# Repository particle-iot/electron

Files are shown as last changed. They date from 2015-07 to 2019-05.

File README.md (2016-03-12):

# Electron

The Electron is a tiny cellular development kit based around U-Blox's SARA U-series (3G) or G-series (2G) cellular modem module and a STM32F205 ARM Cortex M3 microcontroller.

The Electron has a footprint which is a drop-in compatible with the Particle Photon or Core.

Compared to the Particle Photon, the Electron introduces additional hardware features and changes:

1. JST LiPo battery connector.
2. Switch-mode battery charge management and system power path management circuit.
3. Fuel gauge circuit for lithium batteries.
4. Nano-SIM connector.
5. Access to USB data lines. 
6. 12 additional GPIO Pins.
7. 4 additional ADC channels.
8. 6 Timer channels exposed.
9. 2 additional UART peripherals.
10. 1 additional SPI and CAN peripheral.

A detailed description of the pin mapping can be found in **electron-pinmap_v1** spreadsheet.
* Sheet 1: Overview of the Electron pin-out.
* Sheet 2: Overview of the Photon pin-out for comparison.

### Pin Descriptions:
- **VIN:** This is the power supply pin to the Electron with a voltage range of 3.6 to 5.5VDC (internally regulated down to 3.3VDC). When the Electron is powered via its USB port, this pin will *ouput* a voltage of approximately 4.7VDC. Why 4.7 and not 5? Well, the actual voltage will be the USB voltage, which is normally 5, minus the forward voltage drop (0.3V) of the protection diode.
- **RST:** This is an active-low reset pin for the Electron.
- **VBAT:** Supply to the internal RTC, backup registers and SRAM (1.8 to 3.3VDC).
- **3V3:** This pin is the output of the on-board regulator. When powering the Photon via VIN or the USB port, this pin will *output* a voltage of 3.3VDC.
- **WKP:** This is an active-high input that allows you to wakeup the module from sleep/deep sleep modes. When not used as a WAKEUP, this pin can also be used as a digital GPIO, ADC input or PWM.
- **A0 - A5:** These can be used as digital GPIOs, ADC inputs. Alternate functions include: SPI, PWM and DAC.
- **B0 - B5:** These can be used as digital GPIOs, partial ADC inputs, partial PWM outputs.
- **C0 - C5:** These can be used as digital GPIOs.
- **D0 - D7:** These can be used as digital GPIOs. Alternate functions include: UART, SPI, I2C, PWM and CAN. 
- **DAC:** This pin can be used as a digital GPIO, ADC input or as a DAC ouput.
- **RX:** Primarily used as UART RX, but can also be used as a digital GPIO, ADC input or PWM.
- **TX:** Primarily used as UART TX, but can also be used as a digital GPIO, ADC input or PWM.

Please review the pinmap spreadsheet to better understand the alternate functions of the GPIO pins.

### Eagle (schematic, pcb layout and drc):
**eagle** contains the history of Electron designs and **electron_v020** is the latest design.  The **libraries** folder contains the Eagle library for parts used on the Electron.

#License

Designed by Particle. Distributed under a Creative Commons Attribution, Share-Alike license.
Development kits based on this product should be distributed under a similar license.
Commercial products using the Electron as a reference design need not comply with this license; further questions can be sent to hello@particle.io.
Check license.txt for more information.

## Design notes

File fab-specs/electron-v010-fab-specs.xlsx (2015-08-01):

F A B R I C A T I O N D E T A I L S
Customer | : | Particle Industries, Inc.
ATTN | :
Phone # | :
项目名称 Part # | : | electron
版本 Revision | : | v010
层数 # of Layers | : | 4
材料类型 Material Type | : | 370HR
板子厚度 Board Thickness | : | 0.0625"
镀层 Finish Plating | : | ENIG (化镍浸金)
金手指 Gold Fingers | : | 0
板子叠层 Board Stackup | : | 0.018mm - TOP COPPER (GTL) 顶层
 |  | 0.19mm - 7628M/46 x 1
 |  | 0.035mm - LAYER 2 COPPER (G2L) 第二层
 |  | 1.0 to 1.10mm - Core
 |  | 0.035mm - LAYER 3 COPPER (G15L) 第三层
 |  | 0.19mm - 7628M/46 x 1
 |  | 0.018mm - BOTTOM COPPER (GBL) 底层
阻抗控制 Controlled Impedance |  | Yes - 50 ohms on RF Traces (see rf_nets.pdf) 具体参照rf_nets.pdf
介质控制 Controlled Dielectric |  | Yes (part of Controlled Impedance)
最小线宽线距 Min. Width/Spacing | : | 6/6 mils
孔的数量 # Holes | :
最小的孔尺寸 Smallest Hole Size | :
最大的孔尺寸 Largest Hole Size | :
孔的种类 # of Hole Sizes | :
板子尺寸 Board Dimensions | : | 2.03cm x 5.08 cm
排版后的尺寸 Array Size | :
排版的数量 # PCS/Array | : | 10
排版方式 Panelization method | :
插槽 Slots/Cutouts | : | 2 plated slots - 0.020" x 0.047" （2个电镀的槽）
阻焊 Solder Mask | :
丝印 Silk Screen | : | LPI Cyan Top and Bottom（亮青色，参照样品，实际需要用曝光的工艺来做“丝印”）
顶部SMD焊盘的数量 SMD pads Top | :
底部SMD焊盘的数量 SMD pads Bot | :
最小的SMD焊盘的间距 Min. SMD pitch | :
Fabrication | :
齿形的孔 Castellated Holes | : | Yes
最小的齿形空的尺寸Min. Castellated Hole Size | : | 25 mils
电性测试 Electrical Test | : | Yes
订单数量 Quantity |  | 500
交期 Lead Time |  | TBD
Notes:
1) Panelized and v-scored on short sides, routed castellated edges on long sides. 需要进行多片排版，短边留V-CUT的槽，长边沿着齿状边切掉。
2) Do not clip silk screen more than 2-3 mils around exposed copper. 在暴露的铜旁边，对丝印的修剪不可以大于2-3 mils

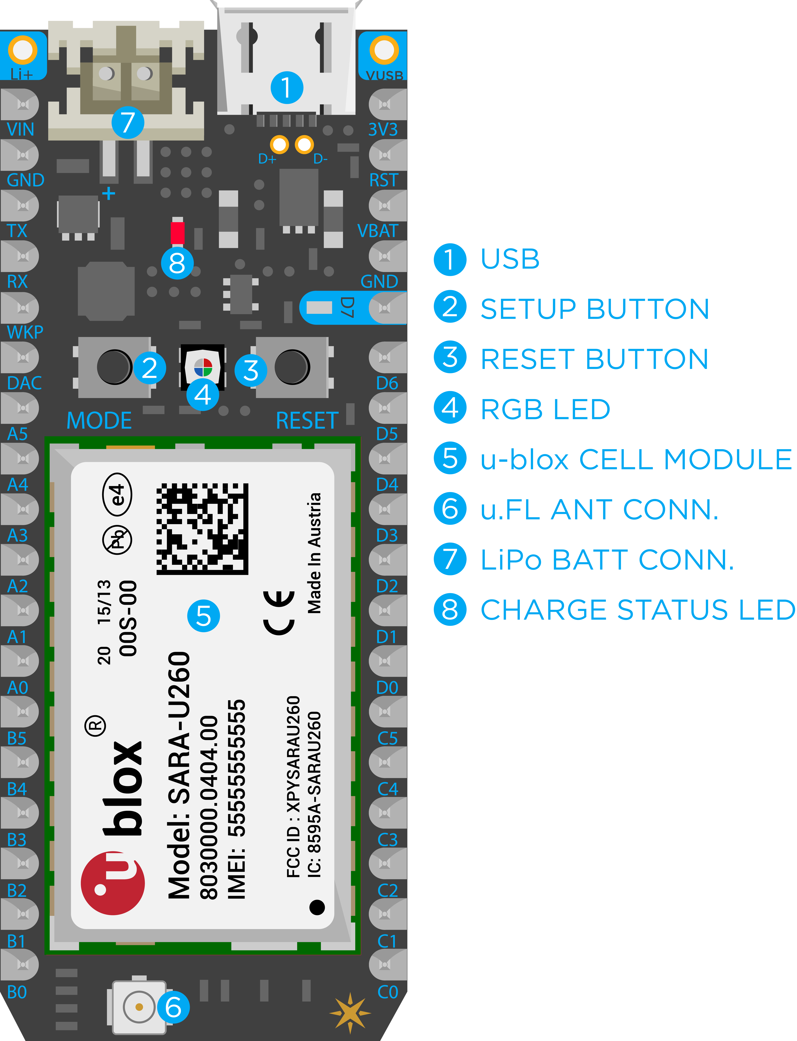
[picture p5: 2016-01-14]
docs/images/electron_pin_markings.png

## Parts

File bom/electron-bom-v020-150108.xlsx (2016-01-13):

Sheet: ELECTRON
 | NAME | ELECTRON
PCBA
 | IDENTIFIER | DESCRIPTION | VALUE | V | A | W | TOL | PACKAGE ID | DESIGNATOR | QTY | MANUFACTURER | MANUFACTURER P/N | CHANGE HISTORY ON 1/8 | CHANGE HISTORY ON 12/8
 | CAPACITOR | Ceramic Capacitor | 0.1uF | 6.3V |  |  | 10% | 0402 | C14, C17, C18, C19, C2, C20, C21, C22, C29, C30, C31, C6, C8, C9 | 14 | Fenghua | 0402B104K160NT
 | CAPACITOR | Ceramic Capacitor | 10nF | 6.3V |  |  | 10% | 0402 | C1, C38 | 2 | Fenghua | 0402B103K500NT
 | CAPACITOR | Ceramic Capacitor, X5R, Low ESR (<70 mΩ) | 10uF | 6.3V |  |  | 10% | 0603 | C23, C24, C27, C40, C41 | 5 | Yageo | CC0603KRX5R5BB106
 | CAPACITOR | Ceramic Capacitor | 12pF | 6.3V |  |  | 10% | 0402 | C33, C34 | 2 | Fenghua | 0402CG120J500NT
 | CAPACITOR | Ceramic Capacitor | 15pF | 6.3V |  |  | 10% | 0402 | C16 | 1 | Fenghua | 0402CG150J500NT
 | CAPACITOR | Ceramic Capacitor | 1uF | 6.3V |  |  | 10% | 0402 | C37, C39 | 2 | Fenghua | 0402X105K6R3NT
 | CAPACITOR | Ceramic Capacitor, X5R, Low ESR (<70 mΩ) | 1uF | ≥25V |  |  | 10% | 0603 | C4 | 1 | Yageo | CC0603KRX5R8BB105
 | CAPACITOR | Ceramic Capacitor, X5R, Low ESR (<70 mΩ) | 2.2uF | 6.3V |  |  | 10% | 0402 | C32, C35 | 2 | Yageo | CC0402KRX5R5BB225
 | CAPACITOR | Ceramic Capacitor | 20pF | 6.3V |  |  | 10% | 0402 | C26, C28 | 2 | Fenghua | 0402CG200J500NT
 | CAPACITOR | Ceramic Capacitor, X5R, Low ESR (<70 mΩ) | 22uF | 6.3V |  |  | 10% | 0603 | C5 | 1 | Samsung | CL10A226KQ8NRNE
 | CAPACITOR | Tantalum Capacitor | 220uF | 6.3V |  |  | 10% | 2312 (6032 metric) | C3 | 1 | AVX | TAJC227K006
 | CAPACITOR | Ceramic Capacitor, X5R, Low ESR (<70 mΩ) | 4.7uF | 6.3V |  |  | 10% | 0402 | C36 | 1 | Samsung | CL05A475KQ5NRNC
 | CAPACITOR | Ceramic Capacitor, X5R, Low ESR (<70 mΩ) | 4.7uF | 6.3V |  |  | 10% | 0603 | C25 | 1 | Yageo | CC0603KRX5R5BB475
 | CAPACITOR | Ceramic Capacitor | 47nF | 6.3V |  |  | 10% | 0402 | C7 | 1 | Fenghua | 0402B473K160NT
 | CAPACITOR | Ceramic Capacitor | 47pF | 6.3V |  |  | 10% | 0402 | C10, C11, C12, C13 | 4 | Fenghua | 0402CG470J500NT
 | CAPACITOR | Ceramic Capacitor | 68pF | 6.3V |  |  | 10% | 0402 | C15 | 1 | Fenghua | 0402CG680J500NT
 | CONNECTOR | JST Connector | 2-pin |  |  |  |  | SMD, 2-pin, Vertical | JP4 | 1 | Kaweei | CW2001-02T-M01-D
 | CONNECTOR | Male Header (0.1" pitch) x 18 pins (B1-B5, A0-A4) | 1x18 |  |  |  |  | 1x18, 0.1" pitch | JP1 | 1 | Kaweei | CP25411-18G-S116A-A
 | CONNECTOR | Male Header (0.1" pitch) x 18 pins (D0-D4, C1-C5) | 1x18 |  |  |  |  | 1x18, 0.1" pitch | JP2 | 1 | Kaweei | CP25411-18G-S116B-A
 | CONNECTOR | USB Micro Connector with Slots, SMD |  |  |  |  |  | USB-MICROB-SLOT-HOLE | X1 | 1 | Kaweei | CMCUSB-5BFM2G-01-D
 | CONNECTOR | uFL Connector, IPEX-20279-001E, SMD |  |  |  |  |  | SMD | J2 | 1 | Kaweei | P1163-0140R
 | CONNECTOR | Nano SIM Card Slot |  |  |  |  |  | 10mm x 12.3mm | J1 | 1 | Kaweei | CSIM2545-06S-D
 | CRYSTAL | 26MHz, 18pF Load Capacitance, SMD5032, 4 pad | 26MHz |  |  |  | <±20ppm | 4-SMD, 5.0 x 3.2mm | Y2 | 1 | Song Ji | SJSMD5026M00018F20
 | CRYSTAL | 32.768KHz, 12.5pF Load Capacitance, SMD3215, 2 pad | 32.768KHz |  |  |  | <±20ppm | 2-SMD, 1.5 x 3.2mm | Y1 | 1 | Song Ji | SJ FC1332K012F520P
 | DIODE | Schottky Diode |  | 30V | 3A |  |  | DO-220AA | U$3 | 1 | Vishay | SS3P3-M3/84A
 | IC | Buffer |  |  |  |  |  | SC-70-5 | U5, U6 | 2 | Texas Instruments | SN74LVC1G07DCKR
 | IC | IC 2-Wire Fuel Gauge |  |  |  |  |  | TDFN-8 | U4 | 1 | Maxim | MAX17043G+T
 | IC | GSM Module |  |  |  |  |  | 16 x 26 x 3mm | U1 | 1 | u-blox | SARA-G350 SARA-U260 SARA-U270
 | IC | IC Bus Transceiver |  |  |  |  |  | 16-UQFN | U2, U8 | 2 | Texas Instruments | SN74AVC4T245RSVR
 | IC | Microcontroller |  |  |  |  |  | LQFP64 | U3 | 1 | ST Microelectronics | STM32F205RGT6TR
 | IC | Power Management IC (PMIC) |  |  |  |  |  | 24VQFN | U$1 | 1 | Texas Instruments | BQ24195RGER
 | IC | Load Switch |  |  |  |  |  | SC70-5 | U9 | 1 | Texas Instruments | TPS22942DCKR
 | IC | Voltage Regulator |  | 1A |  |  |  | 6-SON (2x2) | U$5 | 1 | Texas Instruments | TPS62291DRVR
 | INDUCTOR | Power Wirewound Inductor, 100KHz, Ferrite, 1212 (for 3V3 regulator) | 2.2uH |  | 1.5A |  | 20% | 3.0 mm x 3.0 mm | U$6 | 1 | Taiyo Yuden | NR3015T2R2M
 | INDUCTOR | Power Inductor (for PMIC) | 2.2uH |  | 4A |  |  | 4.45mm x 4.06mm | U$4 | 1 | Bourns, Inc. | SRP4020TA-2R2M
 | LED | Blue, SMD | Blue |  |  |  |  | 0603 | LED1 | 1 | Everlight | 19-217/BHC-ZL1M2RY/3T
 | LED | Red, SMD | Red |  |  |  |  | 0603 | LED3 | 1 | Everlight | 19-217/R6C-AL1M2VY/3T
 | LED | LED RGB, SMD | RGB |  |  |  |  | 4-PLCC (3.2 mm x 2.8mm) | LED2 | 1 | Cree | CLMVB-FKA-CFHEHLCBB7A363
 | PCB | FR4 4-Layer Photon PCB, 2-sided, matte black soldermask, cyan silkscreen |  |  |  |  |  | 20 mm x 50 mm | PCB1 | 1 | Truly
 | RESISTOR | Resistor | 0R |  |  | 1/16W |  | 0201 | R32 | 1 | Fenghua |  | ADDED A NEW PART
 | RESISTOR | Resistor | 100k |  |  | 1/16W | 5% | 0402 | R1 | 1 | Fenghua | RC-02W104JT
 | RESISTOR | Resistor | 10K |  |  | 1/16W | 5% | 0402 | R3, R8, R15, R16, R17, R19, R21, R24, R25, R27, R28, R29, R30, R31 | 14 | Fenghua | RC-02W103JT
 | RESISTOR | Resistor | 150R |  |  | 1/4W | 1% | 0603 | R22 | 1 | Vishay | CRCW0603150RFKEAHP
 | RESISTOR | Resistor | 1K |  |  | 1/16W | 5% | 0603 | R23 | 1 | Fenghua | RC-03K102JT
 | RESISTOR | Resistor | 1K |  |  | 1/16W | 5% | 0402 | R10, R11, R12, R9 | 4 | Fenghua | RC-02W102JT
 | RESISTOR | Resistor | 2.2K |  |  | 1/16W | 5% | 0402 | R4 | 1 | Fenghua | RC-02W222JT
 | RESISTOR | Resistor | 22R |  |  | 1/16W | 1% | 0402 | R5, R6 | 2 | Fenghua | RC-02W22R0FT
 | RESISTOR | Resistor | 330R |  |  | 1/16W | 1% | 0402 | R2 | 1 | Fenghua | RC-02W3300FT
 | RESISTOR | Resistor | 4K7 |  |  | 1/16W | 5% | 0402 | R13, R14 | 2 | Fenghua | RC-02W472JT
 | RESISTOR | Resistor | 5.49K |  |  | 1/16W | 1% | 0402 | R18 | 1 | Fenghua | RC-02W5491FT
 | SWITCH | Tactile Switch, Black Button | 160gF |  |  |  |  | 3.6mm x 3.1mm | MODE, RESET | 2 | Haoyu | TS-1185A-C
ACCESSORIES
 | IDENTIFIER | DESCRIPTION | VALUE | V | A | W | TOL | PACKAGE ID | DESIGNATOR | QTY | MANUFACTURER | MANUFACTURER P/N | CHANGE HISTORY ON 1/8 | CHANGE HISTORY ON 12/8
 | ACCESSORY | Li-Po Battery with JST Connector (2.0mm spacing, 2 pin), 3.7V, 2000mAh |  |  |  |  |  | 51mm x 34mm x 11.3mm | BAT1 | 1 | PKCell | LIPO 103450 2000mAh 3.7V
 | ACCESSORY | Mini Breadboard, White, 400pt tie point, 3.5 x 4.5cm |  |  |  |  |  | 3.5 x 4.5cm | ACC1 | 1 | Ningbo Everest | N/A
 | ACCESSORY | USB Micro-B Cable, 0.5m, White with Molded Logo |  |  |  |  |  | USB Micro-B, 0.5m | ACC2 | 1 | HOP Electronics | N/A
 | ANTENNA | Antenna - Penta band 850/900/1800/1900/2100 MHz |  |  |  |  |  | IPEX MHFI (U.FL) | ANT1 | 1 | Taoglas | PC104.07.0165C
 | DIODE (LED) | White, high brightness | White |  |  |  |  | 5mm DIP |  | 1 | ZHIHENG | ZH-504UW/006-A70
 | RESISTOR | Axial Resistor | 220R |  |  |  |  | Axial DIP |  | 2 | Chianchia | CF1/4W220RJT52
 | RESISTOR | Photoresistor |  |  |  |  |  | 5mm DIP |  | 1 | HAIWANG | MJ5517
 | SIM | Nano SIM Card |  |  |  |  |  | Nano SIM | SIM1 | 1 | Telefonia | N/A
PACKAGING
 | IDENTIFIER | DESCRIPTION | VALUE | V | A | W | TOL | PACKAGE ID | DESIGNATOR | QTY | MANUFACTURER | MANUFACTURER P/N | CHANGE HISTORY ON 1/8 | CHANGE HISTORY ON 12/8
 | PACKAGING | Transparent Plastic Box |  |  |  |  |  | 145 x 90 x 40mm |  | 1 | Youter | YS-E503-1
 | PACKAGING | Internal "ribbon" card stock, cyan with white printing |  |  |  |  |  |  |  | 1 | Mei Ya
 | PACKAGING | Internal anti-static foam insert, top |  |  |  |  |  |  |  | 1 | Sai Fu Ke Si
 | PACKAGING | Internal anti-static foam insert, bottom |  |  |  |  |  |  |  | 1 | Sai Fu Ke Si
 | PACKAGING | Electron Kit Project Card |  |  |  |  |  | Custom |  | 1 | Mei Ya
 | STICKER | "STICK-VINYL-2IN" sticker, 2", Circular, PVC - 5cm |  |  |  |  |  | Circular 2" |  | 1 | Mei Ya
 | PACKAGING | Cardboard box for battery |  |  |  |  |  | TBD |  | 1
 | PACKAGING | Small ziploc static bag for Li-Po battery |  |  |  |  |  |  |  | 1
 | STICKER | "Don't Charge Unattended" Sticker |  |  |  |  |  |  |  | 1
 | STICKER | UPC Sticker for Li-Po Battery (2000mAh) |  |  |  |  |  | 40 mm x 20 mm |  | 1 | Mei Ya | UPC - 724131462352
 | PACKAGING | Small ziploc static bag for starter project components |  |  |  |  |  | 35mm*86mmx0.075mm |  | 1 | Hengmeifeng | ZB2050
 | STICKER | Electron Product Sticker (UPC/Certifications) |  |  |  |  |  |  |  | 1 | Mei Ya | G350 (2G) - 724131462277 U260 (3G N.A.) - 724131462284 U270 (3G World) - 724131462383
 | STICKER | Unique Barcode Sticker (DYMO 30346) |  |  |  |  |  | 1/2" x 1-7/8" |  | 1
 | PACKAGING | Electron box sleeve |  |  |  |  |  |  |  | 1 | Mei Ya
 | PACKAGING | Sticker for SIM card |  |  |  |  |  | 8.5*5.4cm |  | 1 | Mei Ya |  |  | New added part
 | STICKER | UPC Sticker for the Electron |  |  |  |  |  | 40 mm x 20 mm |  | 1 | Mei Ya | G350 (2G) - 724131462277 U260 (3G N.A.) - 724131462284 U270 (3G World) - 724131462383
 | PACKAGING | Transparent Plastic Wrapping |  |  |  |  |  |  |  | 1
 | STICKER | Li-Po Battery Safety Sticker |  |  |  |  |  | 105 x 74mm |  | 1
 | RESISTOR | Resistor | 0R |  |  | 1/16W | 0.05 | 0402 |  | 0 | Fenghua | RC-02000JT

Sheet: CHANGELOG
Subject: | Electron
Project Name: | ELECTRON
BOM Rev.: | 2015-08-20
PCB Rev.: | v011
Date: | 2016-01-08
Prepared by: | Will Hart |  |  |  |  |  | Taoglas | PC104.07.0165C
Project Name |  |  |  | PARTICLE ELECTRON
Item | BOM Revision |  | Project Name | Change Details | Date | Responsible
 | Old | New
1 | electron-bom-v010 | electron-bom-v010-150731 | ELECTRON | Added power, voltage, and tolerance specifications to resistors and capacitors | 2015-07-31 | Will
2 | electron-bom-v010 | electron-bom-v010-150731 | ELECTRON | Changed part number on the Nano SIM from the "loose" to the "tight" connector (CSIM2545-06S-X) | 2015-07-31 | Will
3 | electron-bom-v010 | electron-bom-v010-150731 | ELECTRON | Updated specifications and preferred/alternate part numbers on both power inductors (U$4 and U$6) | 2015-07-31 | Will
4 | electron-bom-v010 | electron-bom-v010-150731 | ELECTRON | Added UPC information to the UPC sticker | 2015-07-31 | Will
5 | electron-bom-v010 | electron-bom-v010-150731 | ELECTRON | Added antenna part specifications to the BOM | 2015-07-31 | Will
6 | electron-bom-v010 | electron-bom-v010-150731 | ELECTRON | Updated Li-Po battery specifications to PKCell part | 2015-07-31 | Will
7 | electron-bom-v010-150731 | electron-bom-v010-150803 | ELECTRON | Updated PMIC Inductor P/N and specs (U$4) | 2015-08-03 | Will
8 | electron-bom-v010-150803 | electron-bom-v010-150805 | ELECTRON | Added MFG and P/Ns for all passive components | 2015-08-05 | Will
9 | electron-bom-v010-150803 | electron-bom-v010-150805 | ELECTRON | Deleted part number U$7 from the BOM | 2015-08-05 | Will
10 | electron-bom-v010-150803 | electron-bom-v010-150805 | BAT2000 | Added BAT2000 SKU tab and populated with BOM items | 2015-08-05 | Will
11 | electron-bom-v010-150803 | electron-bom-v010-150805 | ELECTRON | Updated power tolerances for resistors | 2015-08-05 | Will
12 | electron-bom-v010-150803 | electron-bom-v010-150805 | ELECTRON | Removed 2000mAh hour from ELECTRON BOM and transferred to the BAT2000 BOM | 2015-08-05 | Will
13 | electron-bom-v010-150803 | electron-bom-v010-150805 | ELECTRON | Removed PKG1 and PKG2 (Static bag and static bubble bag) from the ELECTRON BOM | 2015-08-05 | Will
14 | electron-bom-v010-150803 | electron-bom-v010-150805 | TBD | Added TBD section | 2015-08-05 | Will
15 | electron-bom-v010-150805 | electron-bom-v010-150807 | ELECTRON | Updated C5 from 20uF to 22uF to match manufacturer availability | 2015-08-07 | Will
16 | electron-bom-v010-150807 | electron-bom-v010-150812 | ELECTRON | Updated quantity field for resistors and capacitors to match the correct number of designators on the board | 2015-08-12 | Will
17 | electron-bom-v010-150812 | electron-bom-v011-150820 | ELECTRON | Changed the value of C40 and C41 from 2.2uH to 10uH | 2015-08-20 | Will
18 | electron-bom-v010-150812 | electron-bom-v011-150820 | ELECTRON | Added cross part numbers to low ESR parts | 2015-08-20 | Will
19 | electron-bom-v010-150812 | electron-bom-v011-150820 | ELECTRON | Changed the specifications and part number of power inductor for 3V3 inductor (U$6) | 2015-08-20 | Will
20 | electron-bom-v011-150820 | electron-bom-v011-150830 | ELECTRON | Deleted extra antenna P/Ns | 2015-08-23 | Will
21 | electron-bom-v011-150820 | electron-bom-v011-150830 | ELECTRON | Deleted Fenghua cross part numbers on capacitors. | 2015-08-31 | Will
22 | electron-bom-v011-150830 | electron-bom-v012-150908 | ELECTRON | Added new BAT2000 parts to the ELECTRON BOM since it will all be packaged as one unit | 2015-09-08 | Will
23 | electron-bom-v011-150830 | electron-bom-v012-150908 | ELECTRON | Updated part number for C32, C35 to CC0402KRX5R5BB225 to match the 0402 specification | 2015-09-08 | Will
24 | electron-bom-v011-150830 | electron-bom-v012-150908 | ELECTRON | Split 1x18 header into two line items with slightly different part numbers to reflect the different printing requirements | 2015-09-08 | Will
25 | electron-bom-v012-150908 | electron-bom-v015-150922 | ELECTRON | Updated P/N of R18 from RS-02W5491FT to RC-02W5491FT | 2015-09-22 | Will
26 | electron-bom-v015-150922 | electron-bom-v016-151026 | ELECTRON | Updated qty and designators for 0K, 4K7, and 10K resistors | 2015-10-26 | Will
27 | electron-bom-v016-151026 | electron-bom-v017-151102 | ELECTRON | Updated quantity of 10K and 4K7 resistors and deleted all 0R resistors | 2015-11-02 | Mohit
28 |  | electron-bom-v017-151130 | ELECTRON | Updated quantity of 10K resistors from 13 to 14 | 2015-11-30 | Mohit
29 |  | electron-bom-v017-151130 | ELECTRON | Added a new part, load switch - TPS22942DCKR | 2015-11-30 | Mohit
30
31
32
33
34
35
36
37
38
39
40
41
42
43
44
45
46
47
48
49
50
51
52
53
54
55
56
57
58
59
60
61
62
63
64
65
66
67
68
69
70
71
72
73
74
75
76
.end of doc.

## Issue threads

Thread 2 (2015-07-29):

Optimize the solder pads to mitigate risk of contact between solder pins and u-blox module

brandoaire, 2015-07-29:
As soon as we have a proposed solution, let me know so that we can check to be sure it's compatible with whatever the tolerances of the wave solder fixtures is

Closed 2015-07-31.

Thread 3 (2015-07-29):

Current SIM Card holder part doesn't create reliable connection

brandoaire, 2015-07-29:
Going to test the "tighter" version of the Kaweei SIM card slot part first, then can consider GCT part as higher cost alternate.  @jenesaisdiq will ship the parts to @technobly on 7/29

technobly, 2015-08-01:
Tested the 2nd more snug sample, and it's a dang nice sim card holder!  All the problems with the previous one not allowing the card to fully insert are resolved with this one.  And the contacts are smooth and snug.

Closed 2015-08-01.

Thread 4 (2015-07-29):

Expose 5V USB pin alongside D+ and D-?

brandoaire, 2015-07-29:
Would be useful to have a regulated 5V supply now that VIN has a diode on the input line from the USB micro.  Richard suggested placement in line with the header pins in the top right corner, but not populated.

Closed 2015-07-30.

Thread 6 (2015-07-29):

Consolidate passive package sizes

brandoaire, 2015-07-29:
There are a bunch of passives that have both 0603 and 0402 components of the same value.  We can simplify our BOM by consolidating to a single package size.

brandoaire, 2015-07-29:
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

satishgn, 2015-07-30:
0603 footprint is used for certain parts since they are directly connected across high voltage/current 3.8V/3.3V regulator & fuel gauge ICs and using 0402 footprint without sufficient rating could be an issue. Let's discuss tonight and take a decision on this issue.

Closed 2015-07-30.

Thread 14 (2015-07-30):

Test all pins as GPIO to ensure proper connection

technobly, 2015-07-30:
I ran through the pins associated with the Photon on the Electron with the attached test app (D0-D7 and A0-A7), and all of them work except for:

- [x] A0-A7 work as expected.
- [x] D0-D3, D6-D7 work as expected.
- [x] D5 had voltage on it and wouldn't go HI / LOW properly but it does move when commanded
- [x] D4 has 3.3V on it and won't pull low but it wiggles when commanded
- [x] RX, TX work as expected.

These may have some kind of solder issue.  This was v004 Dev Electron, will re-test on v009.
Update: D4/D5 had some soldering or measurement issue because they work fine on v009 hardware.

- [x] Also need to test B0-B5 and C0-C5, not mapped in PIN_MAP yet.
- [x] Update: B0-B5 and C0-C5 work as expected.

```cpp
#include "application.h"

bool s = false;
String command = "";

SYSTEM_MODE(MANUAL);

char lookup[38][16] = {
	"D0  = PB7",
	"D1  = PB6",
	"D2  = PB5",
	"D3  = PB4",
	"D4  = PB3",
	"D5  = PA15",
	"D6  = PA14",
	"D7  = PA13",
	"ID8 = NULL",
	"ID9 = NULL",
	"A0  = PC5",
	"A1  = PC3",
	"A2  = PC2",
	"A3  = PA5",
	"A4  = PA6",
	"A5  = PA7",
	"A6  = DAC = PA4",
	"A7  = WKP = PA0",
	"RX  = PA10",
	"TX  = PA9",
	"SETUP",
	"RGBR",
	"RGBG",
	"RGBB",
	"B0  = PC8",
	"B1  = PC6",
	"B2  = PB0",
	"B3  = PB1",
	"B4  = PC0",
	"B5  = PC1",
	"C0  = PD2",
	"C1  = PC12",
	"C2  = PC11",
	"C3  = PC10",
	"C4  = PB9",
	"C5  = PB8"
};

#if 0
/* TXD_UC        - 36 */ { GPIOB, GPIO_Pin_10, GPIO_PinSource10, NONE, NONE, TIM2, TIM_Channel_3, PIN_MODE_NONE, 0, 0 },
/* RXD_UC        - 37 */ { GPIOB, GPIO_Pin_11, GPIO_PinSource11, NONE, NONE, TIM2, TIM_Channel_4, PIN_MODE_NONE, 0, 0 },
/* RI_UC         - 38 */ { GPIOB, GPIO_Pin_12, GPIO_PinSource12, NONE, NONE, NULL, NONE, PIN_MODE_NONE, 0, 0 },
/* CTS_UC        - 39 */ { GPIOB, GPIO_Pin_13, GPIO_PinSource13, NONE, NONE, NULL, NONE, PIN_MODE_NONE, 0, 0 },
/* RTS_UC        - 40 */ { GPIOB, GPIO_Pin_14, GPIO_PinSource14, NONE, NONE, NULL, NONE, PIN_MODE_NONE, 0, 0 },
/* PWR_UC        - 41 */ { GPIOB, GPIO_Pin_2, GPIO_PinSource2, NONE, NONE, NULL, NONE, PIN_MODE_NONE, 0, 0 },
/* RESET_UC      - 42 */ { GPIOC, GPIO_Pin_4, GPIO_PinSource4, NONE, NONE, NULL, NONE, PIN_MODE_NONE, 0, 0 },
/* LVLOE_UC      - 43 */ { GPIOB, GPIO_Pin_15, GPIO_PinSource15, NONE, NONE, NULL, NONE, PIN_MODE_NONE, 0, 0 },
/* PM_SDA_UC     - 44 */ { GPIOC, GPIO_Pin_9, GPIO_PinSource9, NONE, NONE, NULL, NONE, PIN_MODE_NONE, 0, 0 },
/* PM_SCL_UC     - 45 */ { GPIOA, GPIO_Pin_8, GPIO_PinSource8, NONE, NONE, NULL, NONE, PIN_MODE_NONE, 0, 0 },
/* LOW_BAT_UC    - 46 */ { GPIOC, GPIO_Pin_13, GPIO_PinSource13, NONE, NONE, NULL, NONE, PIN_MODE_NONE, 0, 0 },
#endif

int updatePin(String);

void setup()
{
	Serial.begin(9600);
	//while(!Serial.available()) Spark.process();
	while(Serial.available()>0) Serial.read();
	Serial.print("Enter your desired pin and level (h/l) (e.g. d0h, a3l, t0h, t0l): ");
}

void loop()
{
	s = !s;
	RGB.control(true);
	RGB.color(0,0,0);

	if(Serial.available()) {
		char c = Serial.read();
		if (c != '\r') {
			command += c;
			Serial.print(c); // echo
		}

		if(c == '\r' && command.length() == 3) {
			RGB.color(255,255,255);
			Serial.println(String("\n\rRunning Command: ") + command); // echo

			int pin = updatePin(command);
			if(pin >= 0) {
				Serial.println();
				Serial.println(lookup[pin]);
			}

			command = ""; // clear command

			delay(1000);
			RGB.color(0,0,0);
		}
		else if (c == '\r' && command.length() > 3) {
			command = ""; // clear command
			Serial.println(" <- Bad command bruh");
		}
	}

	RGB.control(false);
}

int updatePin(String command) {
    bool value = 0;
    int pinNumber = command.charAt(1) - '0';
    if (pinNumber < 0 || pinNumber > 7) return - 1;

    if(command.charAt(2) == 'h') value = 1;
    else if(command.charAt(2) == 'l') value = 0;
    else return -2;

    if(command.startsWith("d")) {
    	Serial.print(String("d")+String(pinNumber)+String(value));
        pinMode(pinNumber, OUTPUT);
        digitalWrite(pinNumber, value);
        return pinNumber;
    }
    else if(command.startsWith("a")) {
    	Serial.print(String("a")+String(pinNumber+10)+String(value));
        pinMode(pinNumber + 10, OUTPUT);
        digitalWrite(pinNumber + 10, value);
        return pinNumber + 10;
    }
    else if(command.startsWith("b")) {
    	Serial.print(String("b")+String(pinNumber+24)+String(value));
        pinMode(pinNumber + 24, OUTPUT);
        digitalWrite(pinNumber + 24, value);
        return pinNumber + 24;
    }
    else if(command.startsWith("c")) {
    	Serial.print(String("a")+String(pinNumber+30)+String(value));
        pinMode(pinNumber + 30, OUTPUT);
        digitalWrite(pinNumber + 30, value);
        return pinNumber + 30;
    }
    else if(command.startsWith("w")) {
    	Serial.print(String("w")+String(17)+String(value));
        pinMode(17, OUTPUT);
        digitalWrite(17, value);
        return 17;
    }
    else if(command.startsWith("r")) {
    	Serial.print(String("r")+String(RX)+String(value));
        pinMode(RX, OUTPUT);
        digitalWrite(RX, value);
        return RX;
    }
    else if(command.startsWith("t")) {
    	Serial.print(String("t")+String(TX)+String(value));
        pinMode(TX, OUTPUT);
        digitalWrite(TX, value);
        return TX;
    }
    else return -3;
}
```

technobly, 2015-07-31:
Updated above test app and comments... all external pins tested as GPIO outputs... working 0/3.3V.

Closed 2015-07-31.

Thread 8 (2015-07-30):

Replace 3.3V regulator inductor's package with a slightly larger 0805 footprint pads

satishgn, 2015-07-30:

Closed 2015-07-30.

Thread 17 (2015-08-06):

Need to add orientation indicators to the silkscreen layer for manufacturing

brandoaire, 2015-08-06:
Schottky diode, 0603 LEDs, tantalum capacitor all need orientation indicators.

satishgn, 2015-08-19:
Added orientation indicator for the tantalum capacitor (directly on bPlace layer). Schottky diode & 0603 LEDs already had the indicators on tPlace layer.

Closed 2015-08-19.

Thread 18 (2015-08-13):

Add ESD protection to the u.FL connector area

brandoaire, 2015-08-13:
We discussed with a u-blox tech the possibility of adding ESD protection to the u.FL connector to prevent damage to the internal TX and RX lines of the u-blox module. The details are included in the application notes for the G350 and U260/270.  It would include adding a single capacitor and an inductor, I think. @technobly would know.

technobly, 2015-08-14:
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

C3 and L2 are the required ESD components.
[p.109 - SARA-G3 and SARA-U2 series - System Integration Manual](https://www.u-blox.com/sites/default/files/products/documents/SARA-G3-U2_SIM_(UBX-13000995).pdf)

### C3
SARA:U2: 15 pF Capacitor Ceramic C0G 0402 5% 50 V - GRM1555C1H150J - Murata
SARA-G3: 0 ohm jumper 0402

### L2
SARA:U2: 39 nH Multilayer Inductor 0402 (SRF ~1 GHz) - LQG15HN39NJ02 - Murata
SARA-G3: Do not install

### C2
may not be necessary, double check with u-Blox.

brandoaire, 2015-08-20:
After further discussion, we've decided that that the marginal amount of protection that this will add to the PCB is not worth the expanded board size and potential impact on the RF network.  No need to implement.

Closed 2015-08-20.

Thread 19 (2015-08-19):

Replace LM3281 with TPS62291DRV for 3.3V output

satishgn, 2015-08-19:

satishgn, 2015-08-19:
In the revised circuit both the PMIC and 3.3V regulator inductors use the same 2.2uH value and footprints so BOM should be simpler.

Closed 2015-08-19.

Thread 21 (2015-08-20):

Change 3V3 power inductor footprint

brandoaire, 2015-08-20:
Change from the current Bourns / SRP4020TA-2R2M footprint to the Taiyo Yuden / NR3015T2R2M footprint.

Closed 2015-08-21.

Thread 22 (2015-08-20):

Dick needs to approve the Electron

brandoaire, 2015-08-20:
@jenesaisdiq this one is all you :+1:

jenesaisdiq, 2015-08-20:
Is this just some kind of ceremonial honor? What part of the Electron?

mohitbhoite, 2015-08-20:
ALL of it. The atom.

jenesaisdiq, 2015-08-20:
If I don't approve of the subatomic particle, will our universe wink out?

zsup, 2015-08-20:
that is uncertain.

brandoaire, 2015-08-20:
The next revision of the Electron will be a release candidate.  We need you to look at the current version and provide feedback on any cosmetic or user issues that you notice

technobly, 2015-09-24:
Several versions ahead now...

Closed 2015-09-24.

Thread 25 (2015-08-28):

Increase distance between JST and USB connector

brandoaire, 2015-08-28:
Wilton and Eric believe that there might be some USB alignment issues caused by closeness between the JST and USB connectors

brandoaire, 2015-08-28:
https://s.slack.com/files/wilton/F09N9743Z/2.jpg

brandoaire, 2015-09-02:
From @ericyuanyong

According to the DFM report from ABO, the distance between usb and battery connector is very close which can have a risk that the soldering is not reliable. I check several pcs of beta electron and find out they are almost push each other.

I checked with the pcb file V012 and i think we can still move the battery connector 5mil away from the usb connector

Closed 2015-09-18.

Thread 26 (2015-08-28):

Reduce size of the 2.2uH inductor pad

brandoaire, 2015-08-28:
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

Feedback from beta unit run, line 2

brandoaire, 2015-09-02:
From @ericyuanyong
According to the DFM report from ABO. We need to replace the footprint of Diode(U$3) to avoid the misalign issue for the diode when go through re-flow oven. But In that this footprint was also used on Core and Photon, so should we change it this time.

As the inductor's issue, I remember the reason we changed the footprint of this inductor(U$4) was because we want to have another choice for inductor. So we had decided only use part number for this inductor?

brandoaire, 2015-09-02:
The inductor we purchased was Bourns / SRP4020TA-2R2M

Closed 2015-09-18.

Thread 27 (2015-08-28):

Reduce size of the diode pad

brandoaire, 2015-08-28:
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

Line item #3 on beta unit production feedback

ericyuanyong, 2015-09-02:
I checked the footprint of this diode and find out the package on PCB is the same with the recommendation one in datasheet of this diode.So i don't think we need to change it. We also used this package in Core and Photon. So I'm not quite sure this is really a problem or not.

brandoaire, 2015-09-04:
@ericyuanyong @technobly (Brett) has some reasons to believe that a change is necessary--he's going to add more details here, but if you'd give the changes a try and commit the edits for review on your day Monday, it'd be appreciated!

technobly, 2015-09-04:
@ericyuanyong the thing that's happening with the diode that because there is no thermal relief, copper has filled in completely around the pad.  Because the solder mask is larger than the defined top copper pad, the resulting composite PCB has a much larger top copper pad that was intended.  This is allowing the part to slide around too much during reflow.

To resolve this, we can create a version of the diode that is to be used in no thermal relief situations, and add a `_NT` (no thermal) suffix to the part name.  This will be handy for other parts as well so we should standardize the suffix.  We just need to back calculate the sizes since the solder mask is auto generated by Eagle.  Reduce the new top copper pad size for the new _NT part so that the resulting new solder mask is the same size as the old top copper.  I want to say the soldermask is about a 4 mil anualar ring around the pad size (might be 0.1mm though)... but you'll have to check.

Closed 2015-09-18.

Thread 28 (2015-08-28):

Figure out how to solder pins for the Electron

brandoaire, 2015-08-28:

brandoaire, 2015-08-28:
Brainstorming from 8/28
- 3D solder mask made from a thin stainless steel that separates the module from the pins
- Peelable solder mask or expoxy or glue that can be applied to the module after SMT and before wave solder that prevents solder from touching the pads of the module
- ublox module hat for manual soldering to prevent flux and solder bridges
- Trim up the pads on the bottom of the ublox module and place a strip of soldermask.

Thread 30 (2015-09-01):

Footprint issues for Diode and inductor

ericyuanyong, 2015-09-01:
According to the DFM report from ABO. We need to replace the footprint of Diode(U$3) to avoid the misalign issue for the diode when go through re-flow oven. But In that this footprint was also used on Core and Photon, so should we change it this time.
   As the inductor's issue, I remember the reason we changed the footprint of this inductor(U$4) was because we want to have another choice for inductor. So we had decided only use part number for this inductor?

Closed 2015-09-02.

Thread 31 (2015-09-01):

Distance issue between usb connector and battery connector

ericyuanyong, 2015-09-01:
According to the DFM report from ABO, the distance between usb and battery connector is very close which can have a risk that the soldering is not reliable. I check several pcs of beta electron and find out they are almost push each other.
     I checked with the pcb file V012 and i think we can still move the battery connector 5mil away from the usb connector

Closed 2015-09-02.

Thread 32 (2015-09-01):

Distance issue between usb connector and battery connector

ericyuanyong, 2015-09-01:
According to the DFM report from ABO, the distance between usb and battery connector is very close which can have a risk that the soldering is not reliable. I check several pcs of beta electron and find out they are almost push each other.
     I checked with the pcb file V012 and i think we can still move the battery connector 5mil away from the usb connector

Closed 2015-09-01.

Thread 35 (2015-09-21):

Confusing Silkscreen

brandoaire, 2015-09-21:
We've received feedback from beta testers that the silkscreen markings are confusing, since they lie in between pins.  Potential solutions:

- adding a small triangular arrow pointing up or down next to the label?

monkbroc, 2015-09-21:
Another reason for the confusion is that some labels are "above" the pin (VIN, 3V3) while most are "below".

brandoaire, 2015-09-21:
Hey @monkbroc that specific issue has been fixed in subsequent versions of the hardware.

monkbroc, 2015-09-21:
:+1: @brandoaire

technobly, 2015-09-24:
I literally spent 60 seconds making this so please forgive me!  But what about just a blob of silkscreen that helps to tie the label to the pin above it?  Arrows would be hard to see... but this might work.
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

monkbroc, 2015-09-24:
That would be good. I would have understood that intuitively.

kennethlimcp, 2015-09-25:
I just realized the header are labeled on the inside. Can we have them shown outside instead?

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

jenesaisdiq, 2015-09-25:
Obviously a manufacturing error, @kennethlimcp. Won't be like that in production.

technobly, 2015-09-25:
You've Cat 2 B Kitten Me!!! WAT.  I knew we were working on this and scratch tested samples.  I've been developing with 2 production Beta Electrons and have not noticed those labels until RIGHT MEOW.  :joy_cat:

kennethlimcp, 2015-09-25:
This might be a good resolution in addition to a silkscreen improvement :)

monkbroc, 2015-09-25:
That is bananas! I've never see that done before! I thought about labels on the side of the headers but didn't realize it could actually be done :smile:

Yeah, consider this issue closed! (just make sure the labels are on all pins instead of just some)

brandoaire, 2015-09-25:
Awww we were hoping to keep this as a surprise :-) don't tell!

technobly, 2015-09-25:
Shred the files, shred the files!!

kennethlimcp, 2015-09-25:
:fire :rabbit: gone!

mohitbhoite, 2015-11-30:
closing this issue now, header labels FTW

Closed 2015-11-30.

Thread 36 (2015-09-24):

Eagle u-blox layout part mislabed pins

monkbroc, 2015-09-24:
I was looking at the Eagle layout for the Electron and noticed that pins 22-23 in the top right corner of the u-blox part should be labeled 21-22.

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

technobly, 2015-09-24:
Nice catch @monkbroc, that's my bad :)

mike-u, 2016-10-14:
Has this been solved yet? It doesn't seem to be in the current v020 but I'm having a really hard time selecting the text to delete it or edit it.

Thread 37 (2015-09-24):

Make u-blox GPS communication pins available

monkbroc, 2015-09-24:
The u-blox cellular module can work in tandem with a u-blox GPS module through the DDC pins (SDL and SDA, pins 26, 27). Can you consider making those pins available to the outside world through user pins? B0 and B1 seem convenient from the layout perspective.

It will make it easier to add an integrated GPS solution.

DDC pins allow -0.3 V to 3.6 V and are tristate without pull-up at reset so they wouldn't interfere with B0/B1 unless enabled through u-blox AT commands.

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

andyw-lala, 2015-09-24:
I see where you're going with this.. :)

On Thu, Sep 24, 2015 at 4:11 PM, Julien Vanier <notifications@github.com>
wrote:

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

--
Andy

technobly, 2015-09-24:
>I see where you're going with this.. :)

I see what you did there ;-)

---

This is a great suggestion as it would make it easier to operate GPS modules, the u-blox module will automatically intialize and talk to u-blox GPS receivers.  If you don't use a u-blox module though it might not work well?  There also might be some other required signals to expose and components to add to make this really a drop in solution:
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
cc: @mohitbhoite @jenesaisdiq

mohitbhoite, 2015-09-24:
This is a good suggestion and can be executed with minimal intrusion to the existing setup. I wonder we if have enough bandwidth to test this setup before committing a hardware change.

alan707, 2015-09-24:
> This is a good suggestion and can be executed with minimal intrusion to the existing setup. I wonder we if have enough bandwidth to test this setup before committing a hardware change.
+1 that would be awesome guys!

monkbroc, 2015-09-25:
> I don't think we'd want to rely on that fact... two pins shorted together that can be set to opposing states (HIGH/LOW), will be set to opposing states eventually :) :zap: :fire:

My point was: if somebody doesn't enable the DDC pins they will be tristate so the user firmware can use B0 and B1 as either inputs or outputs. If someone uses the DDC pins, the firmware can force B0 and B1 to be tristate to avoid the :zap:

Regarding the other signals, could GPIO2, 3, 4 also be made available on other header pins?

All the orange components in the picture could be added on an external board as not to increase the cost of the Electron itself.

technobly, 2015-09-28:
I ran across this and thought I would share.  I just skimmed it a bit to learn more about what makes GNSS advantageous.  I didn't get a full picture, but it seems like there are some power saving features that may be duplicatable without a GNSS receiver and also sounded like there is a way that the cellular modem can automatically download some data over the cellular network instead of from satellites to speed up the initialization process.  Not sure if I skimmed that correctly though.
https://www.u-blox.com/sites/default/files/GNSS-Implementation_AppNote_(UBX-13001849).pdf

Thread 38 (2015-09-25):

Consider reducing R13/14

andyw-lala, 2015-09-25:
10K is high even for 3.3V @ 400KHz.

Recommend 4.7K or 3.6K for increased margin.

monkbroc, 2015-09-25:
This is I2C, right? I believe the max rise time allowed is 1us so 4.7K or less sound correct.

mohitbhoite, 2015-09-25:
I agree, 10K seems high at 400K. The datasheet schematic example uses 10K. This app note was useful: http://www.ti.com/lit/an/slva689/slva689.pdf

mohitbhoite, 2015-11-30:
updated design to use 4K7

Closed 2015-11-30.

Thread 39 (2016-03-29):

Cloud variables and functions inaccessible even though Electron is online

BobGlicksman, 2016-03-29:
I have encountered two instances to date where I cannot access any cloud functions or variables on my Electron, even though the dashboard shows the Electron as online and I can retrieve the list of cloud functions and variables from the particle cloud.  I have verified that my firmware is running OK on the Electron and the multicolor LED is breathing cyan (and the battery charge LED is off showing that the battery is fully charged).  This happens after a few days of operation.  The only way to get accessibility back is to reset the Electron (either via the reset button or by flashing code to it OTA).

In addition to finding and fixing this problem, I would like to suggest the following improvements to the dashboard:
1.  Have the "Last Connection" display the date/time of the last time that the Electron communicated with the cloud.  Right now, it seems to show the time of the last reset (which is also useful).
2.  Indicate (on the dashboard) if any cloud variables or functions (particle.variable() or particle.function()) are not accessible, even though they are registered in the cloud.
3.  provide a means to remotely reset an Electron from the dashboard without having to flash new firmware to it (which is expensive, data-wise).

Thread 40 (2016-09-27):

Serial1 doesn't work below 1200 BAUD

andrey-gvrd, 2016-09-27:
[Documentation ](https://docs.particle.io/reference/firmware/electron/#serial) indicates that 300 and 600 BAUD rates are supported, but it doesn't work (receiving garbage data).

Using [this dongle](https://www.sparkfun.com/products/13746) to connect UART to computer. Chip on it supports >= 300 BAUD.

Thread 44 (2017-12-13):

For future revision expose RI_UC

ScruffR, 2017-12-13:
This would help combining wake on ring/sms and external trigger and also a ring/sms wake from deep sleep with a (inverting) bridge RI_UC to WKP.

ScruffR, 2017-12-13:
Parallel issue for E-Series https://github.com/spark/e-series-evaluation-board/issues/1

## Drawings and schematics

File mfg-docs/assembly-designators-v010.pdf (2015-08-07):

## LED3

# ELECTRON - TOP

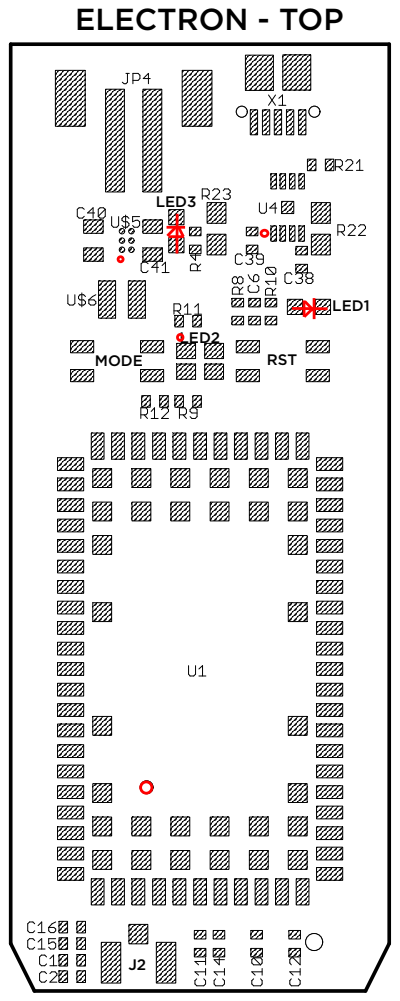
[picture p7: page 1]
LED1; MODE; RST; LED2

U$4 | C7
C25 C5 | C4

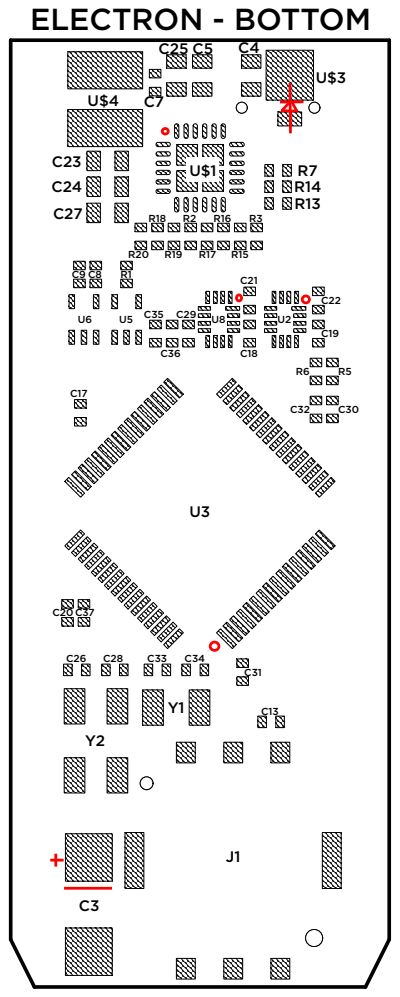
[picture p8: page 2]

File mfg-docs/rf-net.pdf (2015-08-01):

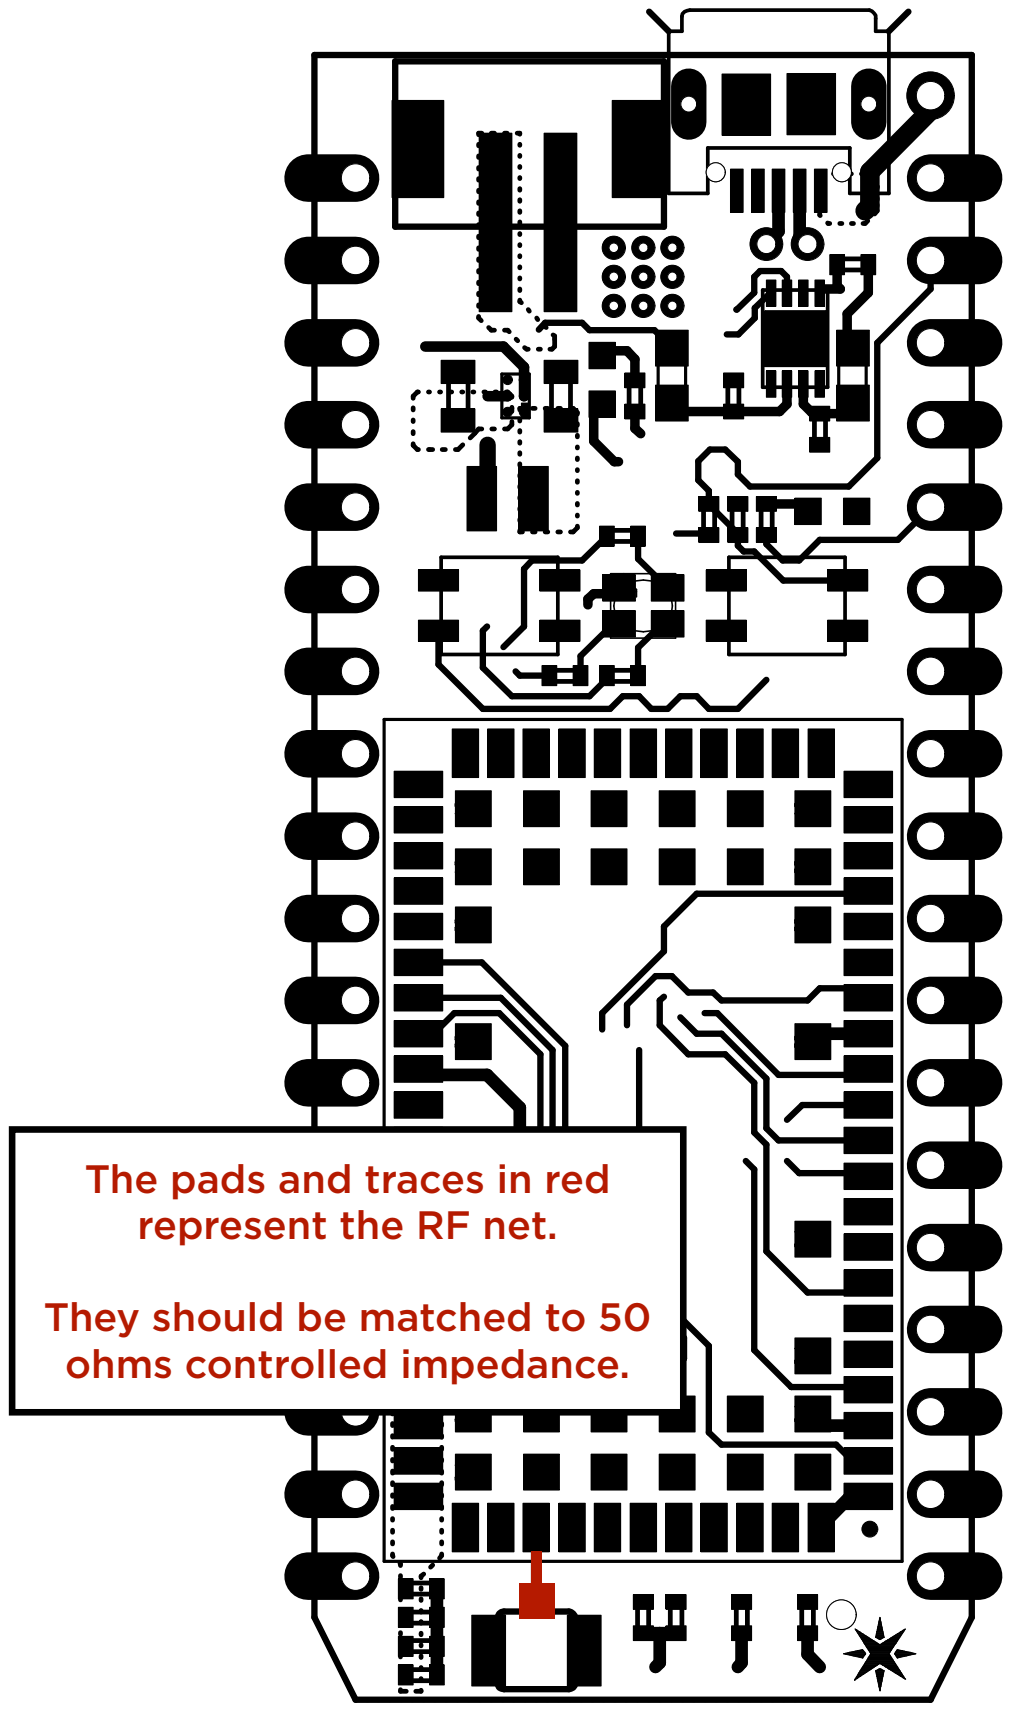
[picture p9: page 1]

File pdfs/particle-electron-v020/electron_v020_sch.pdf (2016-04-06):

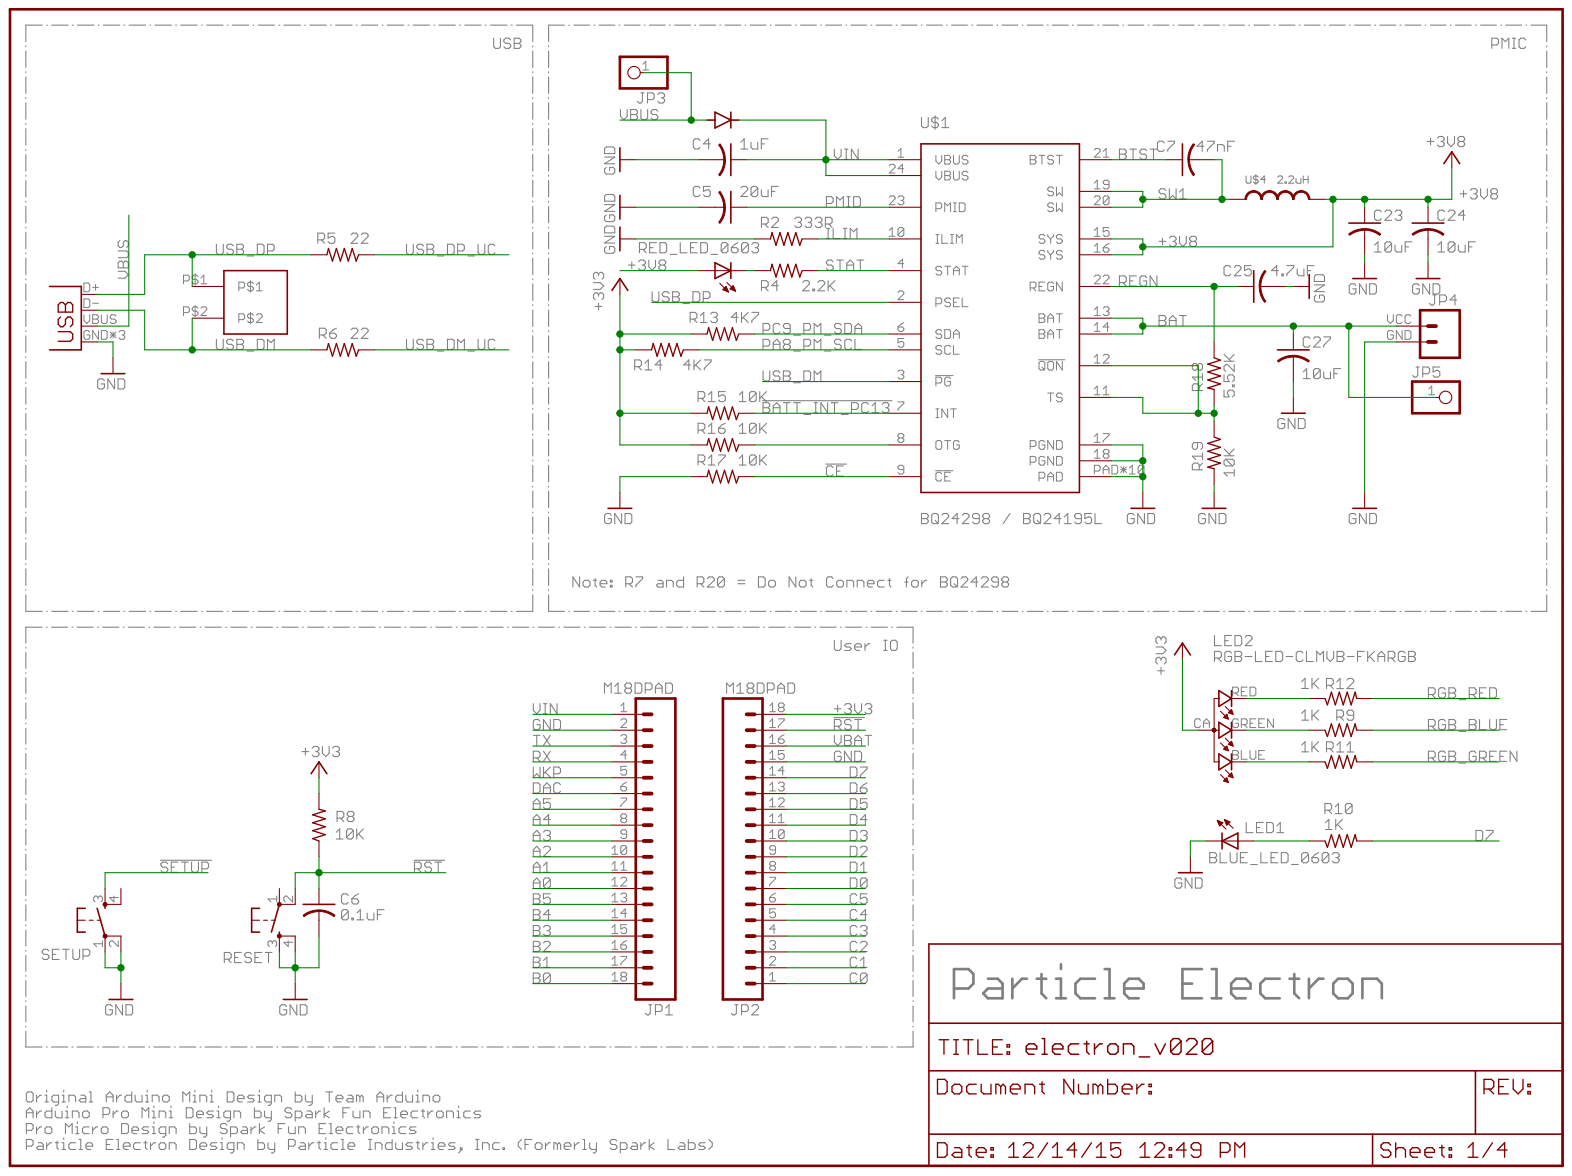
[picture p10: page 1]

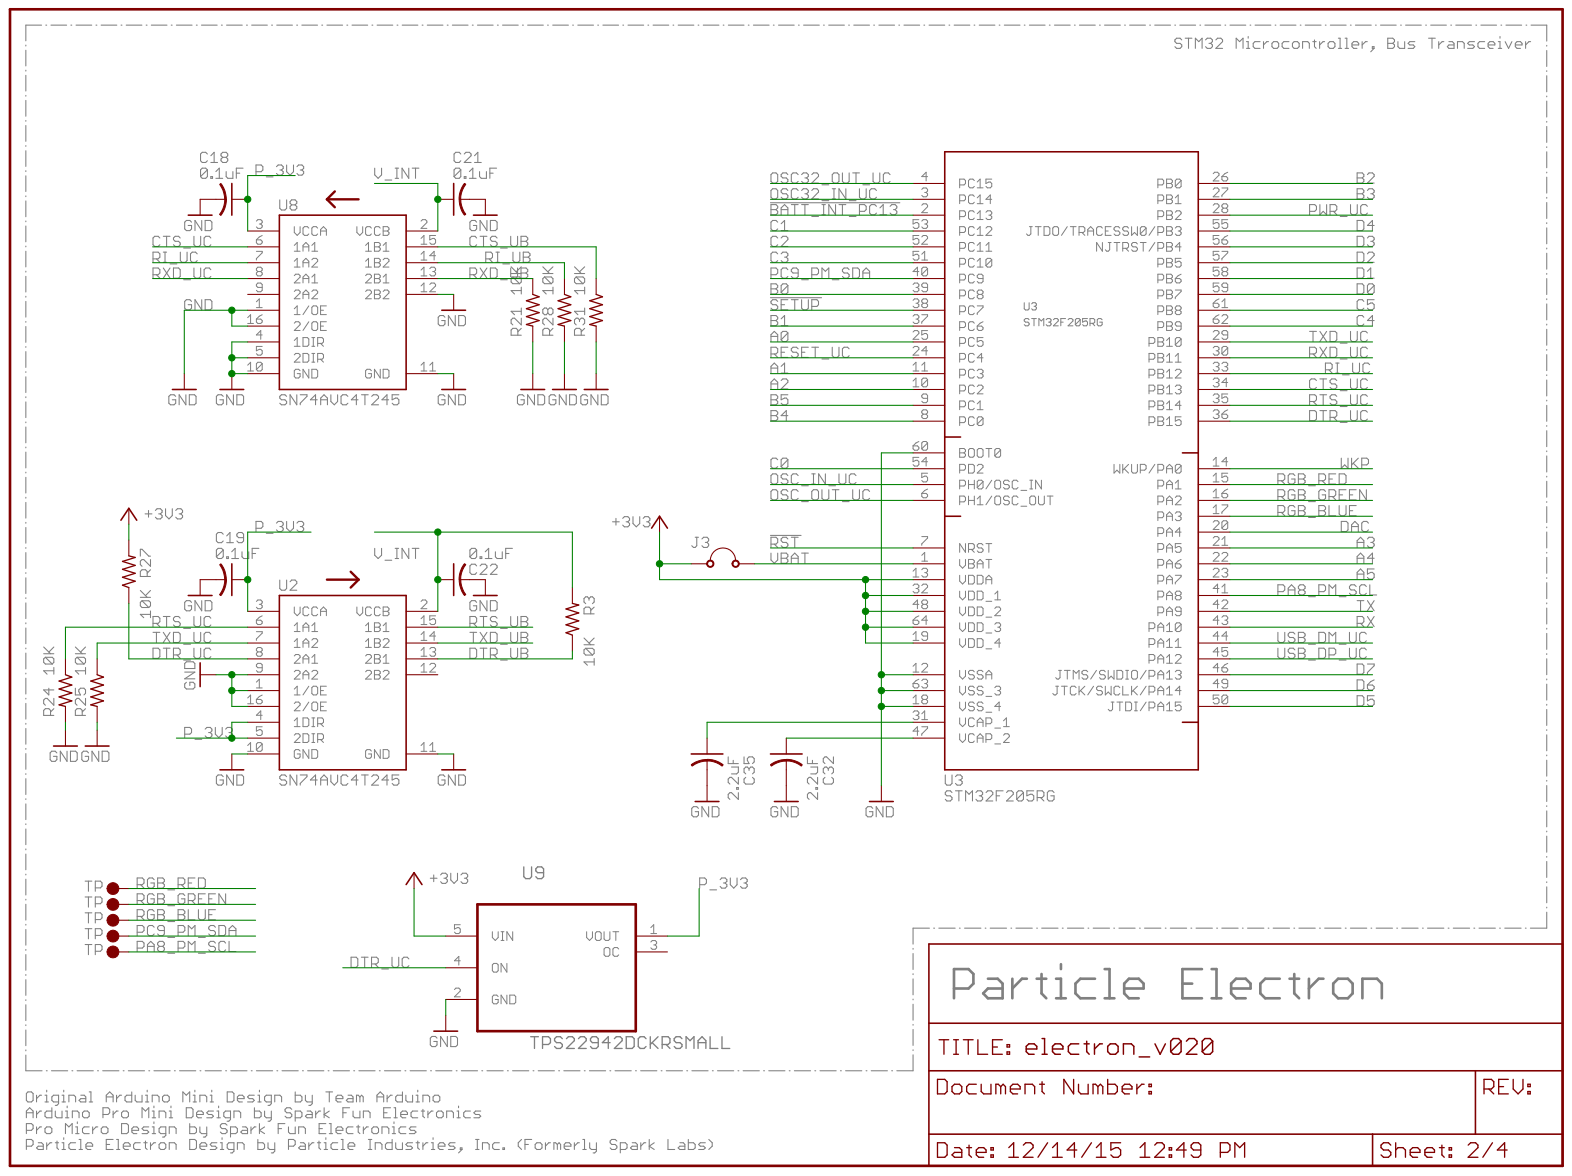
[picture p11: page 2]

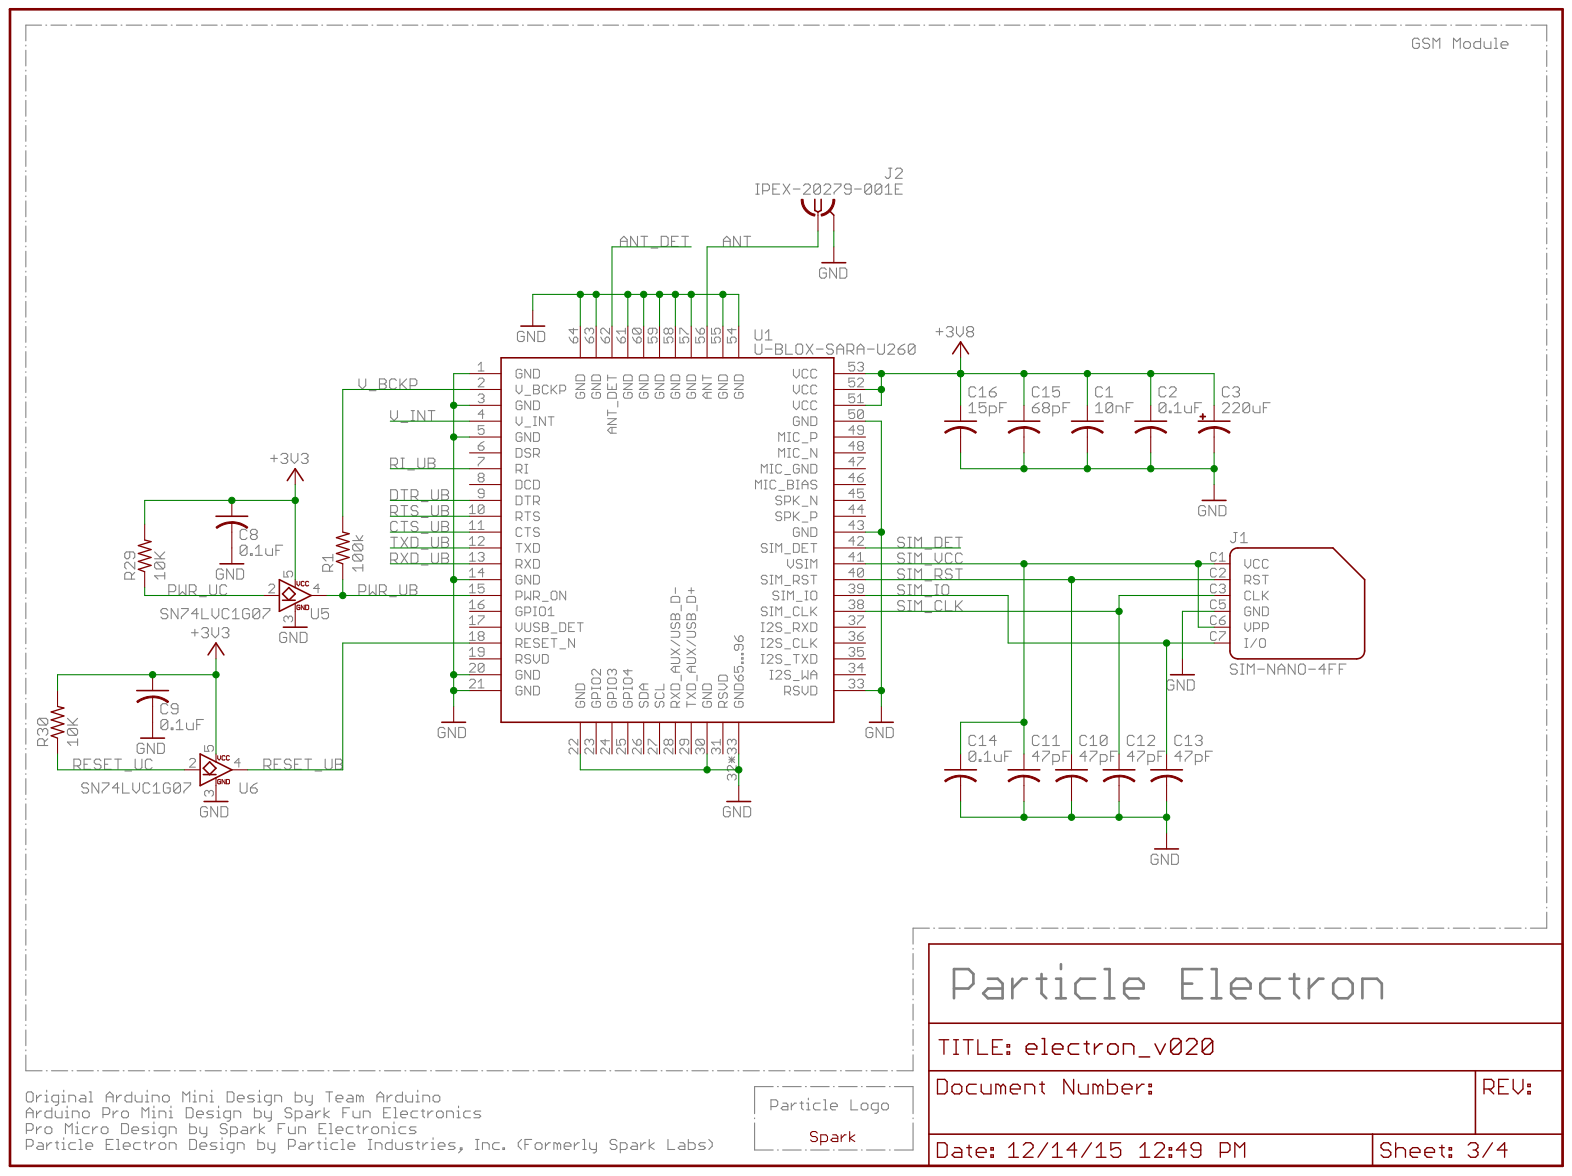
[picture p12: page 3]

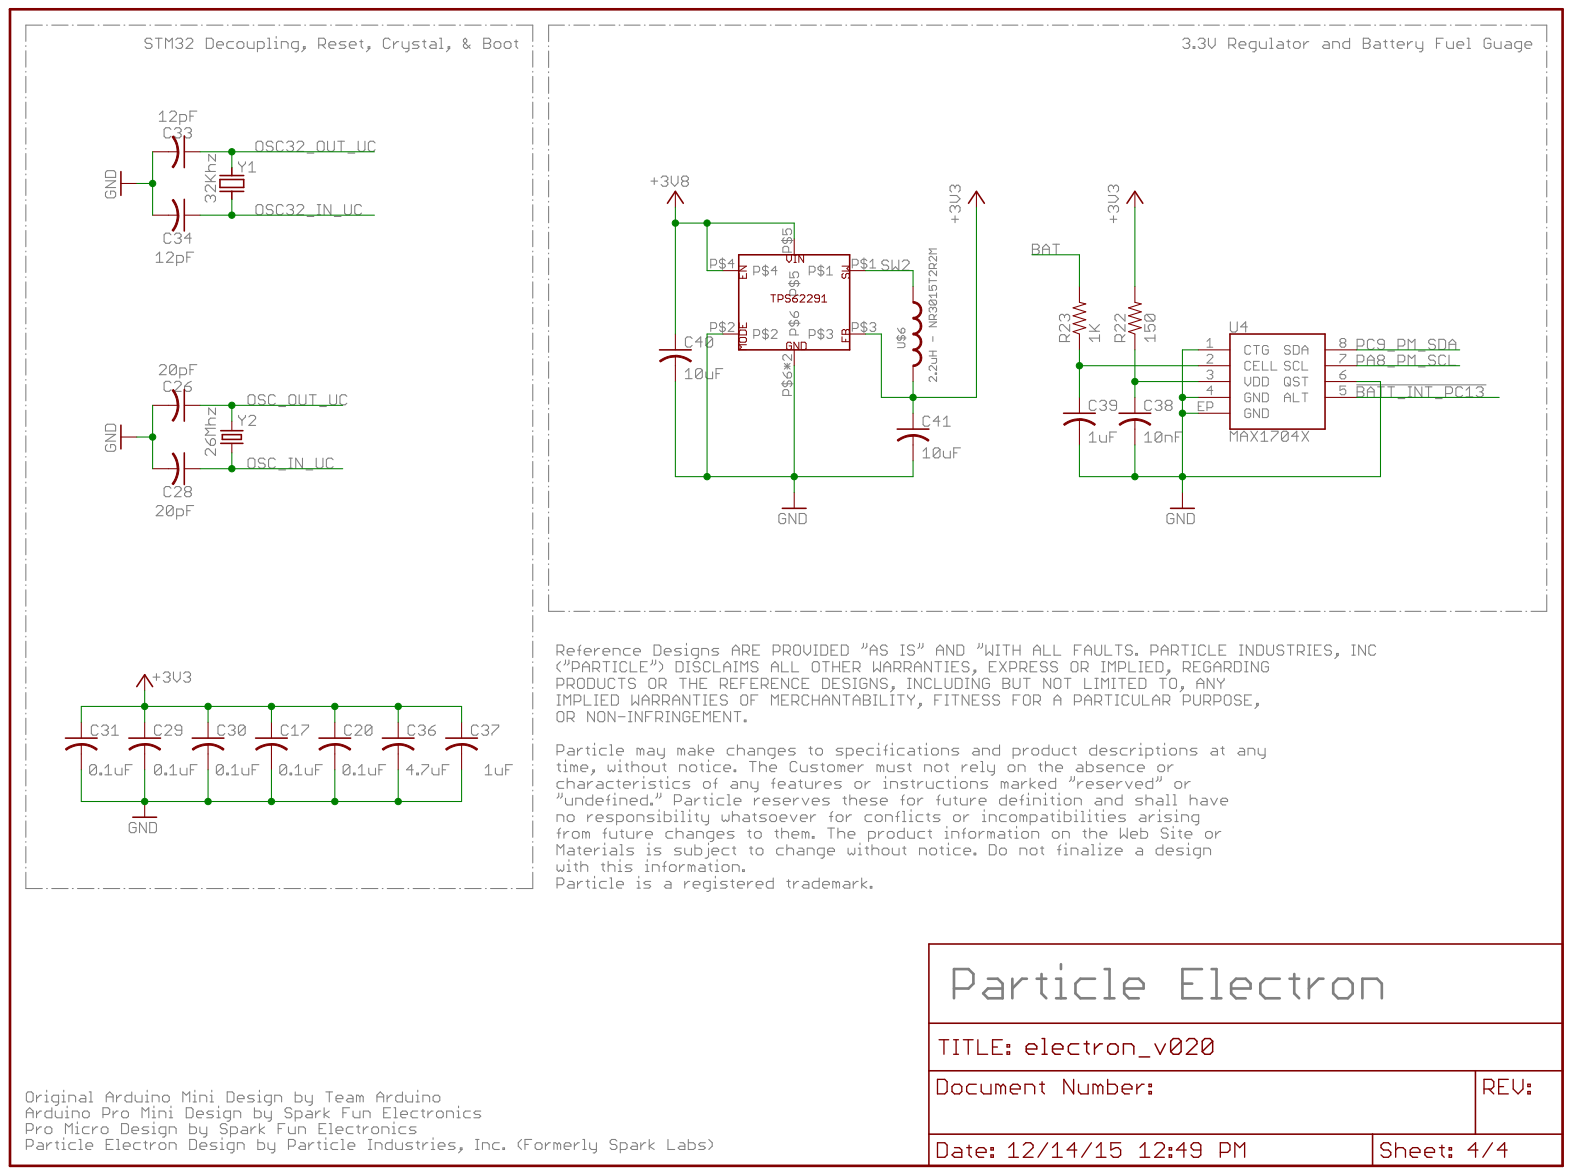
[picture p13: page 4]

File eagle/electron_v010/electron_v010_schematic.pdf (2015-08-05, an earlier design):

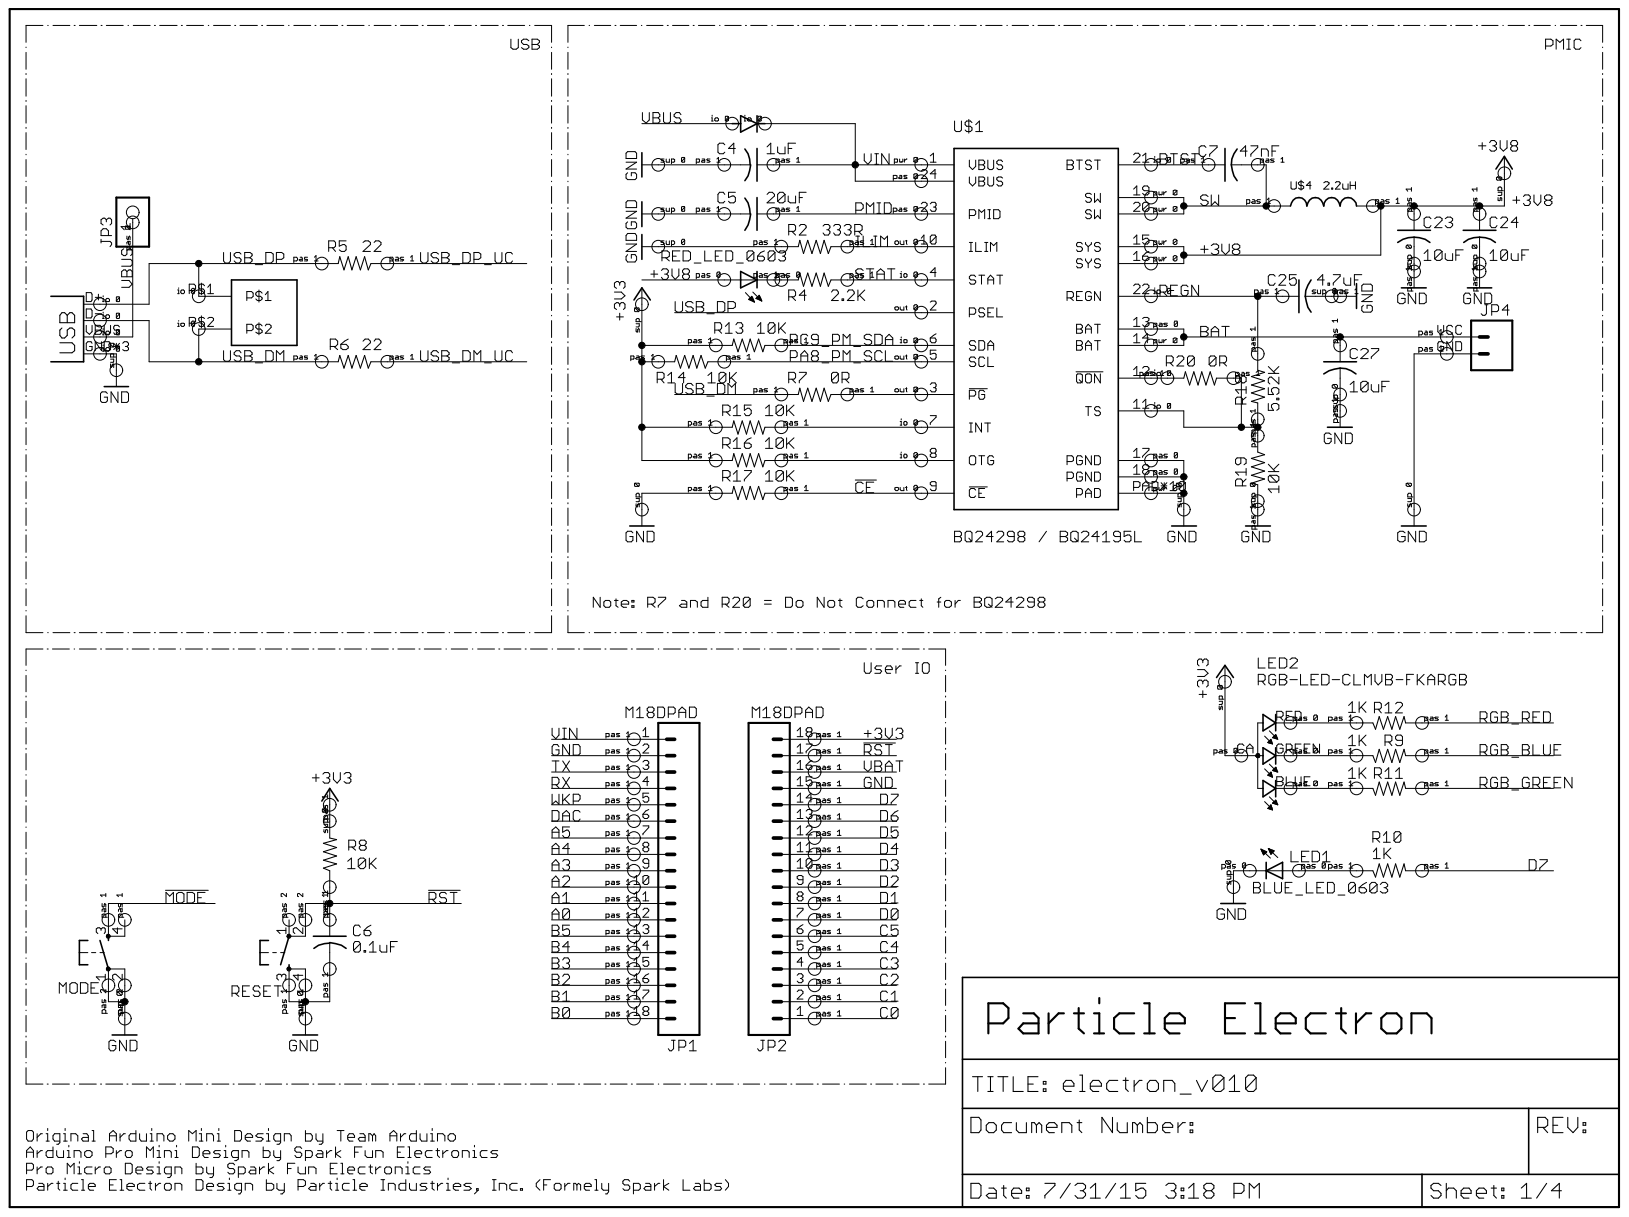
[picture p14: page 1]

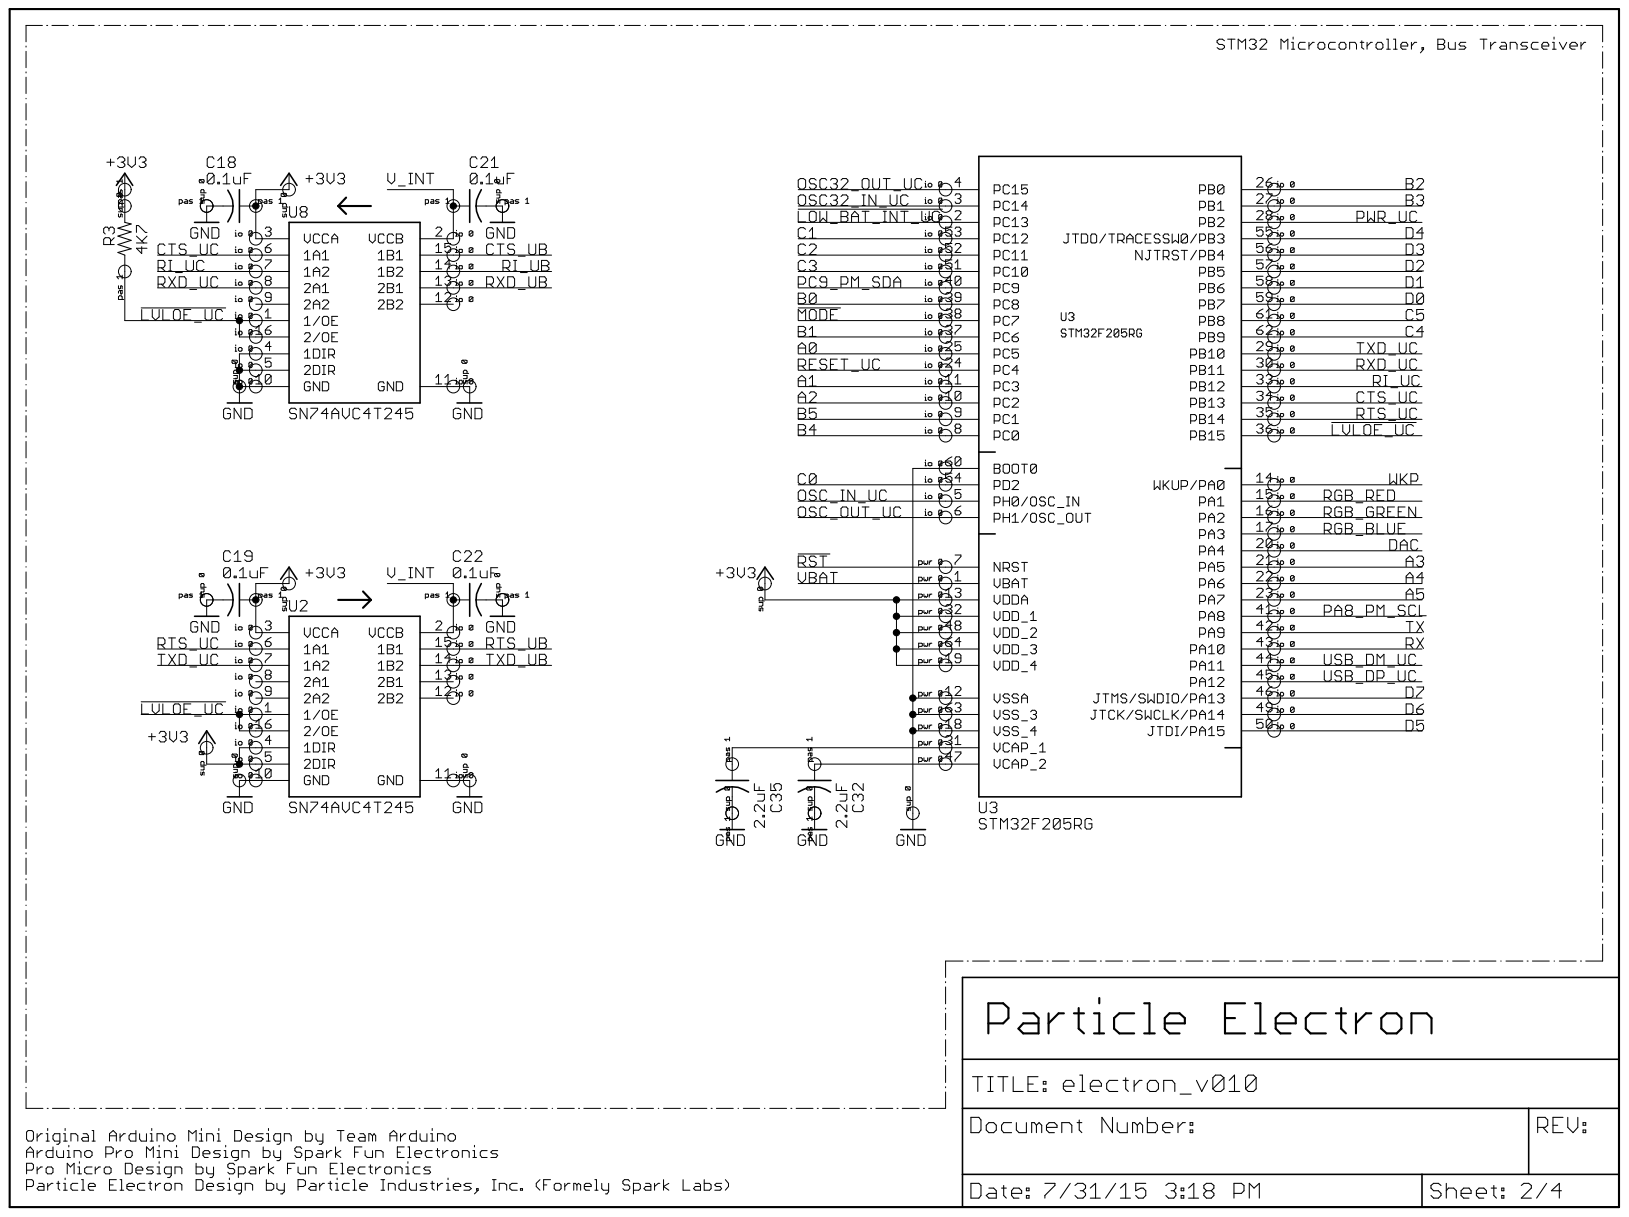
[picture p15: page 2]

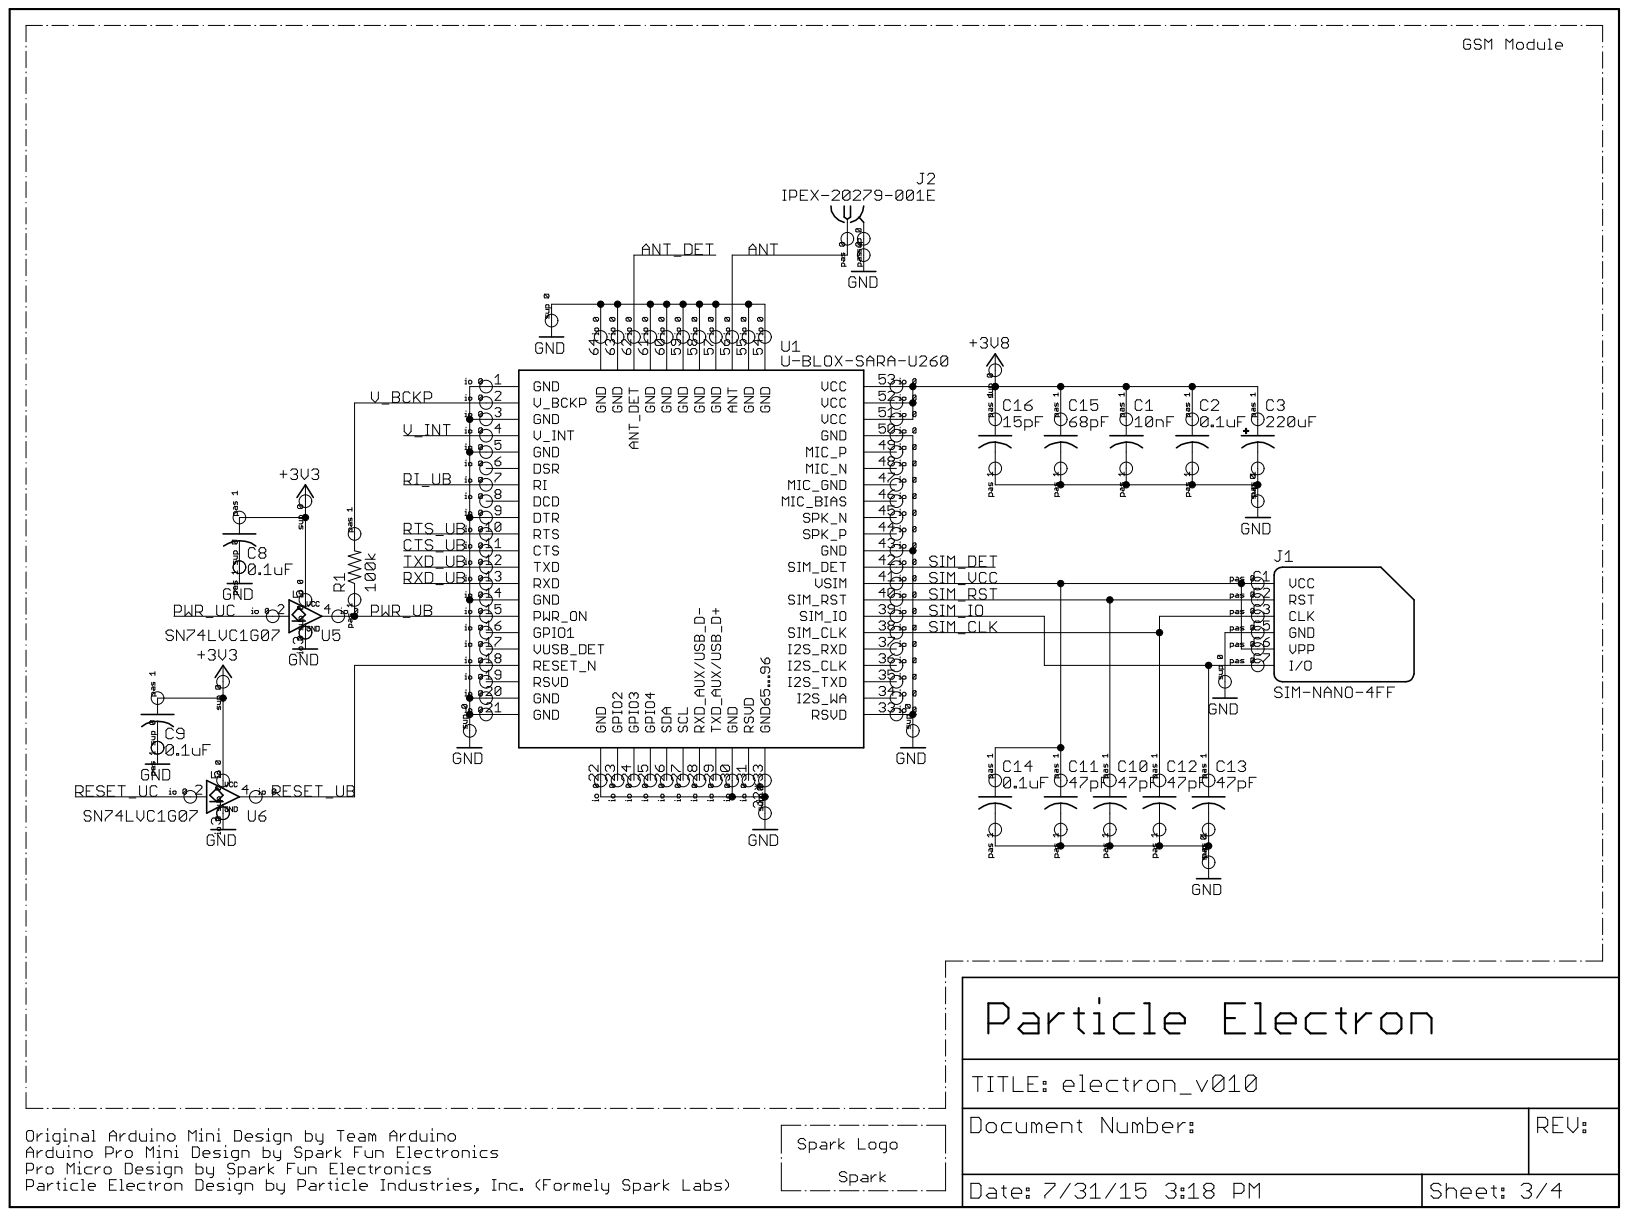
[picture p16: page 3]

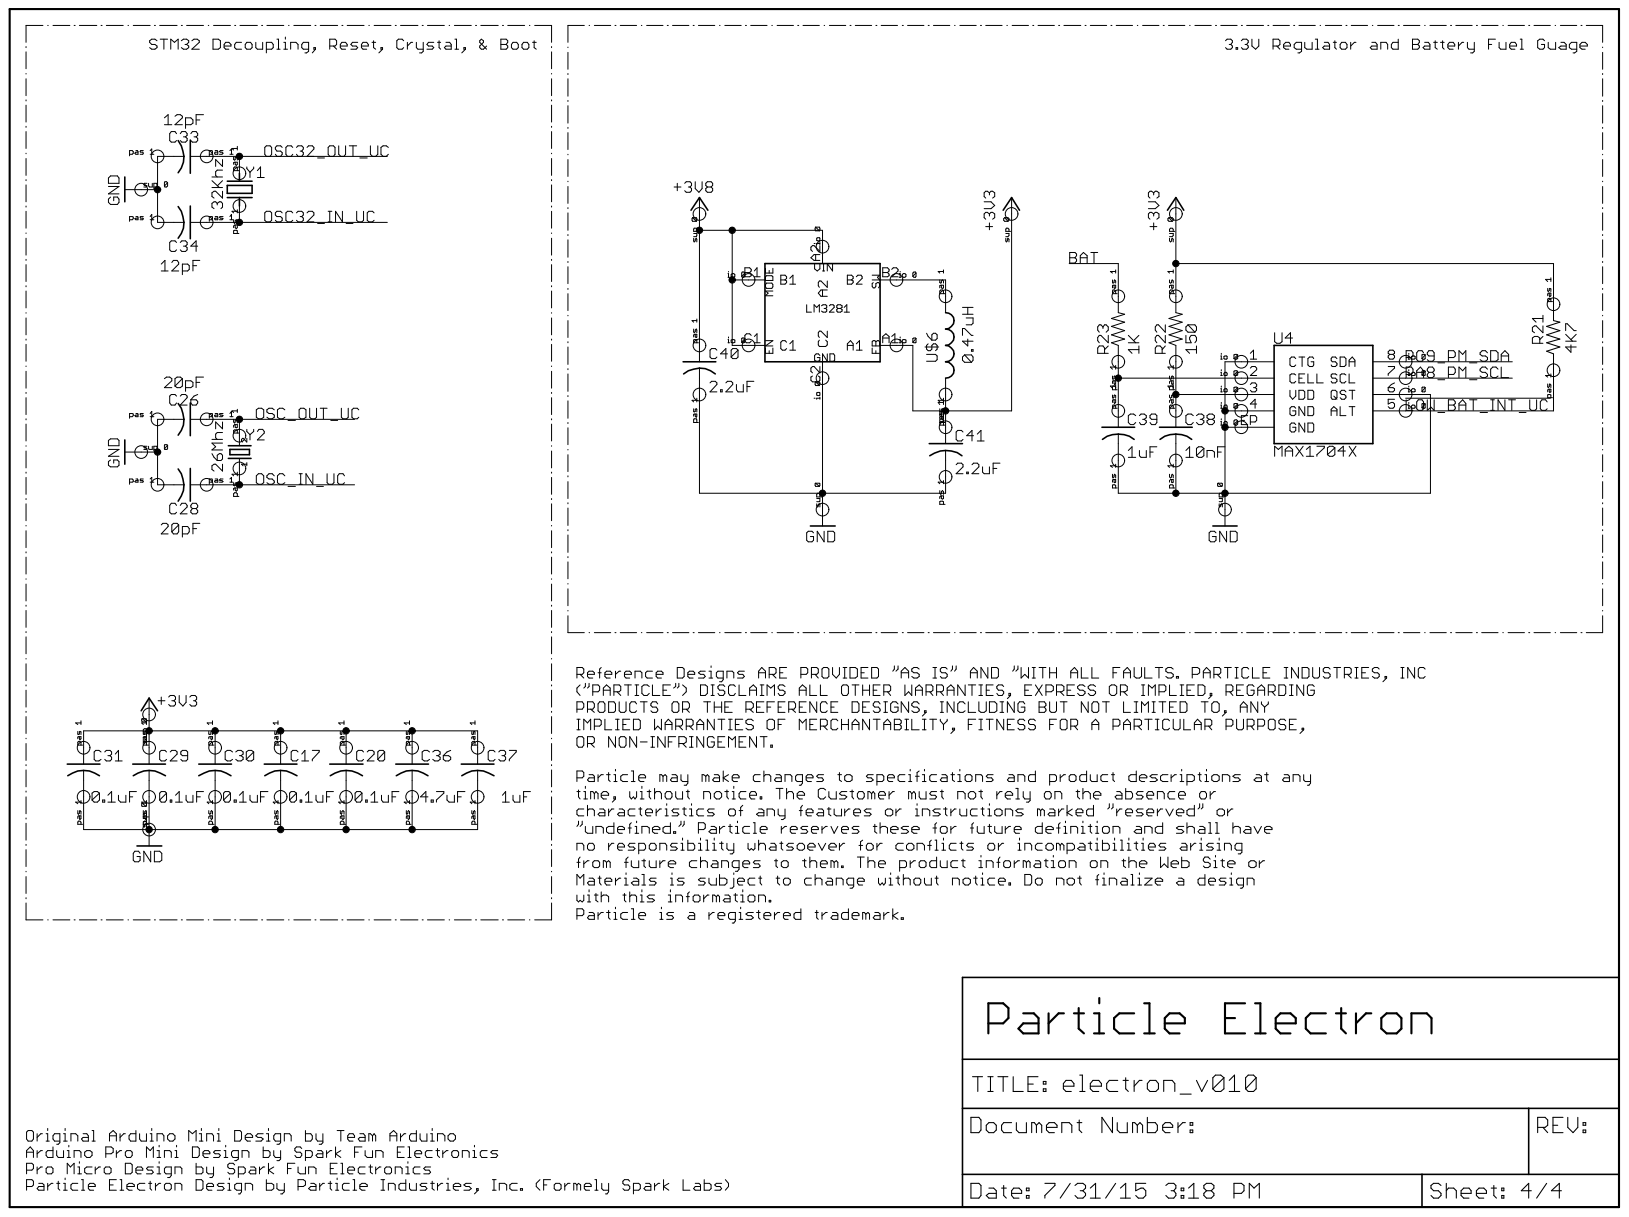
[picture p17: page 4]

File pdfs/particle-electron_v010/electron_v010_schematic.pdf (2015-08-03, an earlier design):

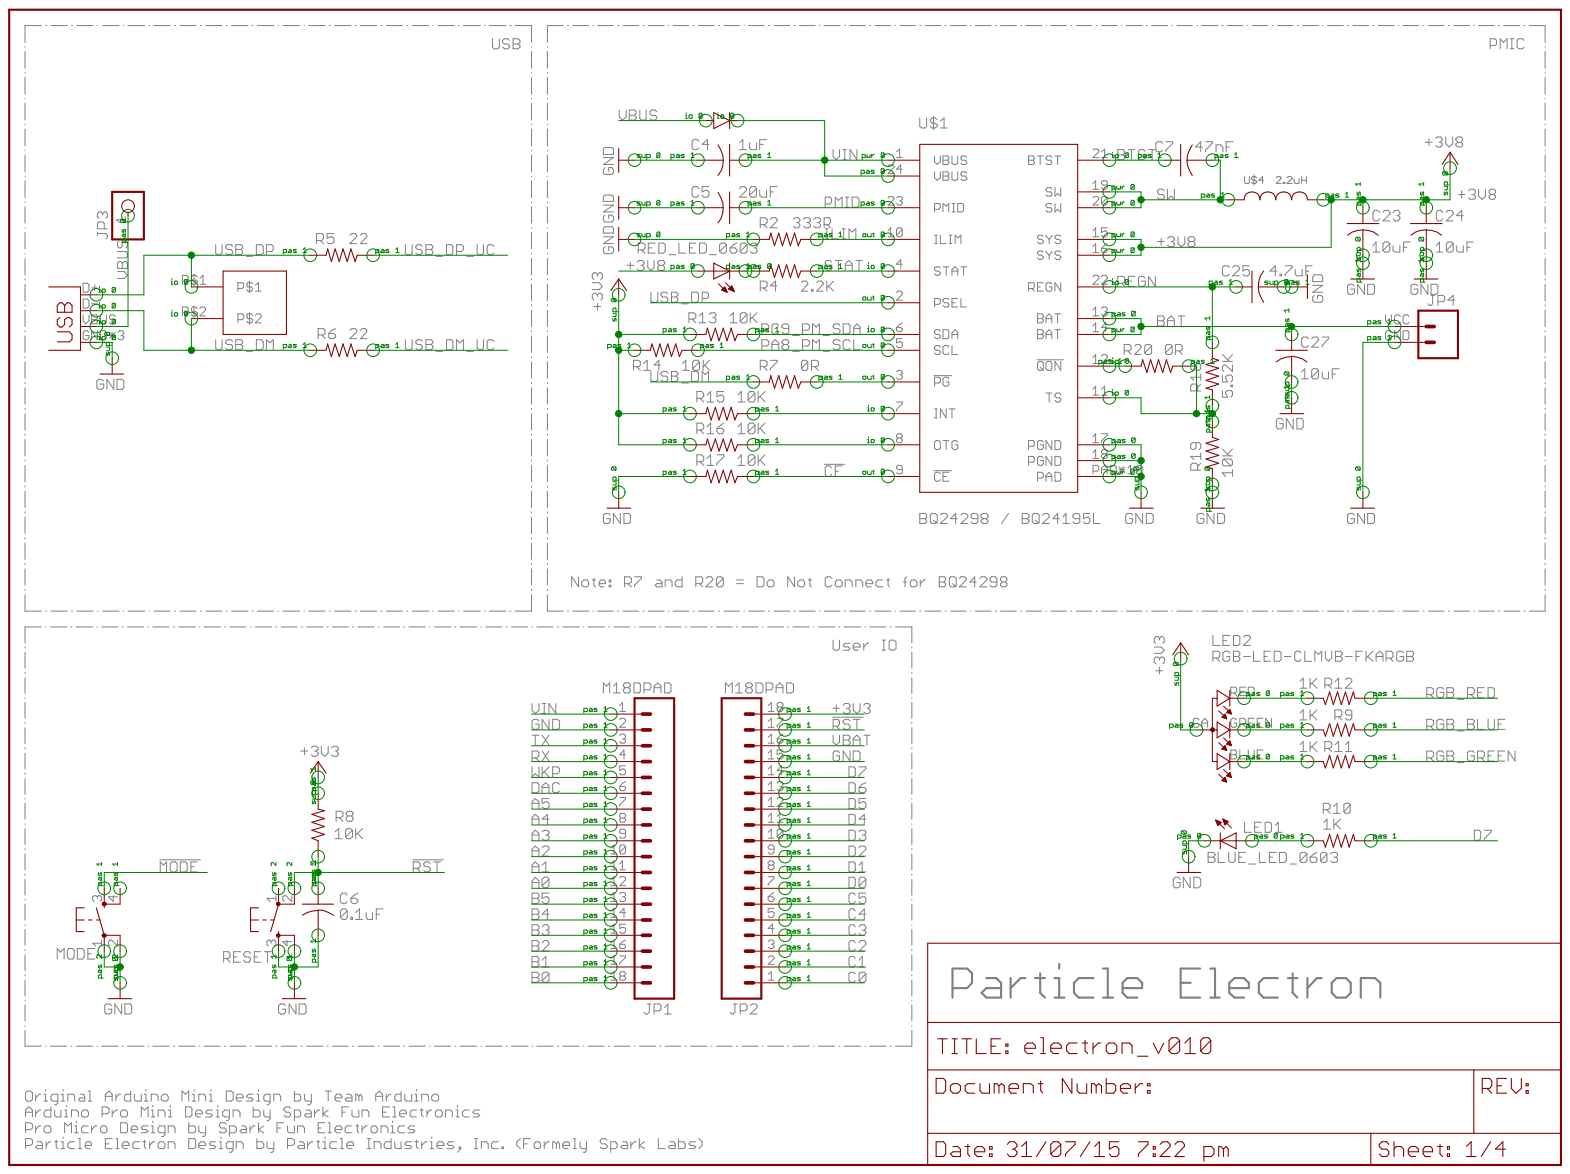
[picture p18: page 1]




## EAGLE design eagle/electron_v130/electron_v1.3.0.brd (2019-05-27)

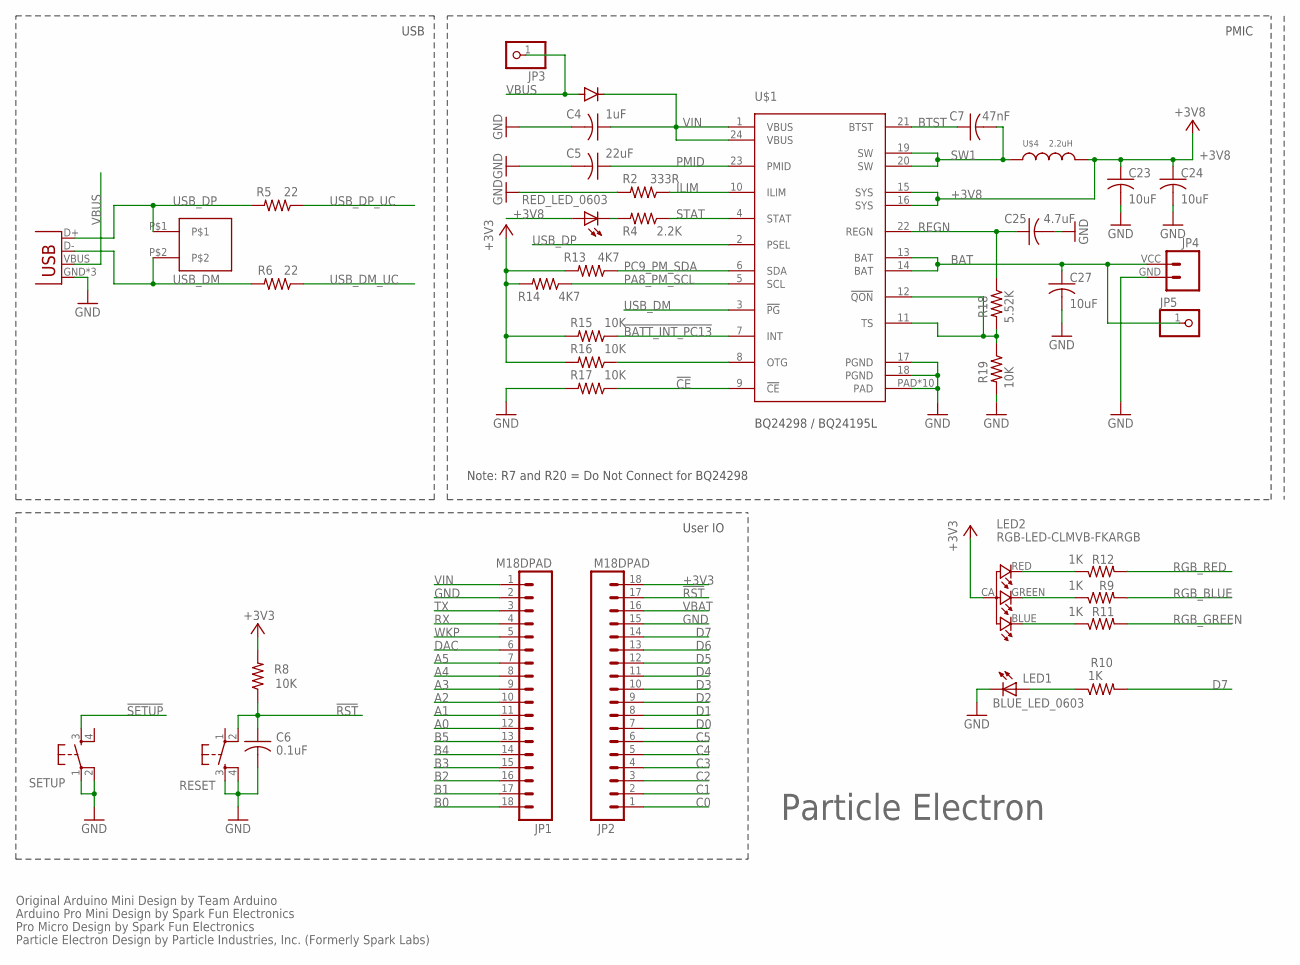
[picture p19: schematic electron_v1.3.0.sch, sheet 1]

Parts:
BLUE_LED_0603: LEDNOSILK; LED-0603-NS
C4: 1uF; C0603_B
C5: 22uF; C0603_B
C6: 0.1uF; C0402_B
C7: 47nF; C0402_B
C23, C24, C27: 10uF; C0603_B
C25: 4.7uF; C0603_B
JP1, JP2: M18DPAD; 1X18-D-PADS
JP3, JP5: PINHD-1X1NOSILK; 1X01_NO_SILK
JP4: M024UCON-15767; JST-2-SMD-VERT
LED2: RGB-LED-CLMVB-FKARGB; PLCC4-2MM-RGB
R2: 333R; R0402_B
R4: 2.2K; R0402_B
R5, R6: 22; R0402_B
R8, R15, R16, R17, R19: 10K; R0402_B
R9, R10, R11, R12: 1K; R0402_B
R13, R14: 4K7; R0402_B
R18: 5.52K; R0402_B
RED_LED_0603: LED0603; LED-0603
RESET: KMR211GLFS; TACTILE_SWITCH_SMD
SETUP: KMR211GLFS; TACTILE_SWITCH_SMD
U$1: BQ24298 / BQ24195L; QFN24
U$3: DIODE_NT; DIODE-DO-220AA_NT(SMP)
U$4: 2.2uH; INDUCTOR-4040
U$7: M02_0.05_HEADER
X1: USB-MICROB; USB-MICROB-SLOT-HOLE

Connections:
!BATT_INT_PC13: R15.1, U$1.7 (INT); also elsewhere on the board
!CE: R17.1, U$1.9 (!CE)
!RST: C6.1, JP2.17, R8.1, RESET.2; also elsewhere on the board
!SETUP: SETUP.3; also elsewhere on the board
+3V3: JP2.18, LED2.CA (1), R8.2, R13.2, R14.2, R15.2, R16.2; also elsewhere on the board
+3V8: C23.1, C24.1, RED_LED_0603.A, U$1.15 (SYS), U$1.16 (SYS), U$4.P$2 (2); also elsewhere on the board
A0: JP1.12; also elsewhere on the board
A1: JP1.11; also elsewhere on the board
A2: JP1.10; also elsewhere on the board
A3: JP1.9; also elsewhere on the board
A4: JP1.8; also elsewhere on the board
A5: JP1.7; also elsewhere on the board
B0: JP1.18; also elsewhere on the board
B1: JP1.17; also elsewhere on the board
B2: JP1.16; also elsewhere on the board
B3: JP1.15; also elsewhere on the board
B4: JP1.14; also elsewhere on the board
B5: JP1.13; also elsewhere on the board
BAT: C27.1, JP4.VCC (2), JP5.1, U$1.13 (BAT), U$1.14 (BAT); also elsewhere on the board
BTST: C7.1, U$1.21 (BTST)
C0: JP2.1; also elsewhere on the board
C1: JP2.2; also elsewhere on the board
C2: JP2.3; also elsewhere on the board
C3: JP2.4; also elsewhere on the board
C4: JP2.5; also elsewhere on the board
C5: JP2.6; also elsewhere on the board
D0: JP2.7; also elsewhere on the board
D1: JP2.8; also elsewhere on the board
D2: JP2.9; also elsewhere on the board
D3: JP2.10; also elsewhere on the board
D4: JP2.11; also elsewhere on the board
D5: JP2.12; also elsewhere on the board
D6: JP2.13; also elsewhere on the board
D7: JP2.14, R10.2; also elsewhere on the board
DAC: JP1.6; also elsewhere on the board
GND: BLUE_LED_0603.C, C4.2, C5.2, C6.2, C23.2, C24.2, C25.2, C27.2, JP1.2, JP2.15, JP4.GND (1), R2.2, R17.2, R19.2, RESET.3, RESET.4, SETUP.1, SETUP.2, U$1.17 (PGND), U$1.18 (PGND), U$1.PAD, U$1.PAD@1 (PAD), U$1.PAD@2 (PAD), U$1.PAD@3 (PAD), U$1.PAD@4 (PAD), U$1.PAD@5 (PAD), U$1.PAD@6 (PAD), U$1.PAD@7 (PAD), U$1.PAD@8 (PAD), U$1.PAD@9 (PAD), X1.GND, X1.MT1 (GND), X1.MT2 (GND); also elsewhere on the board
ILIM: R2.1, U$1.10 (ILIM)
LED1: BLUE_LED_0603.A, R10.1
unnamed: R4.2, RED_LED_0603.C
unnamed: R16.1, U$1.8 (OTG)
unnamed: LED2.BLUE (2), R11.1
unnamed: LED2.GREEN (3), R9.1
unnamed: LED2.RED (4), R12.1
PA8_PM_SCL: R14.1, U$1.5 (SCL); also elsewhere on the board
PC9_PM_SDA: R13.1, U$1.6 (SDA); also elsewhere on the board
PMID: C5.1, U$1.23 (PMID)
REGN: C25.1, R18.1, U$1.22 (REGN)
RGB_BLUE: R11.2; also elsewhere on the board
RGB_GREEN: R9.2; also elsewhere on the board
RGB_RED: R12.2; also elsewhere on the board
RX: JP1.4; also elsewhere on the board
STAT: R4.1, U$1.4 (STAT)
SW1: C7.2, U$1.19 (SW), U$1.20 (SW), U$4.P$1 (1)
TS: R18.2, R19.1, U$1.11 (TS), U$1.12 (!QON)
TX: JP1.3; also elsewhere on the board
USB_DM: R6.2, U$1.3 (!PG), U$7.P$2, X1.D-
USB_DM_UC: R6.1; also elsewhere on the board
USB_DP: R5.2, U$1.2 (PSEL), U$7.P$1, X1.D+
USB_DP_UC: R5.1; also elsewhere on the board
VBAT: JP2.16; also elsewhere on the board
VBUS: JP3.1, U$3.ANODE, X1.VBUS
VIN: C4.1, JP1.1, U$1.1 (VBUS), U$1.24 (VBUS), U$3.CATHODE
WKP: JP1.5; also elsewhere on the board

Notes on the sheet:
PMIC
User IO
USB
Particle Electron
Note: R7 and R20 = Do Not Connect for BQ24298
Original Arduino Mini Design by Team Arduino
Arduino Pro Mini Design by Spark Fun Electronics
Pro Micro Design by Spark Fun Electronics
Particle Electron Design by Particle Industries, Inc. (Formerly Spark Labs)

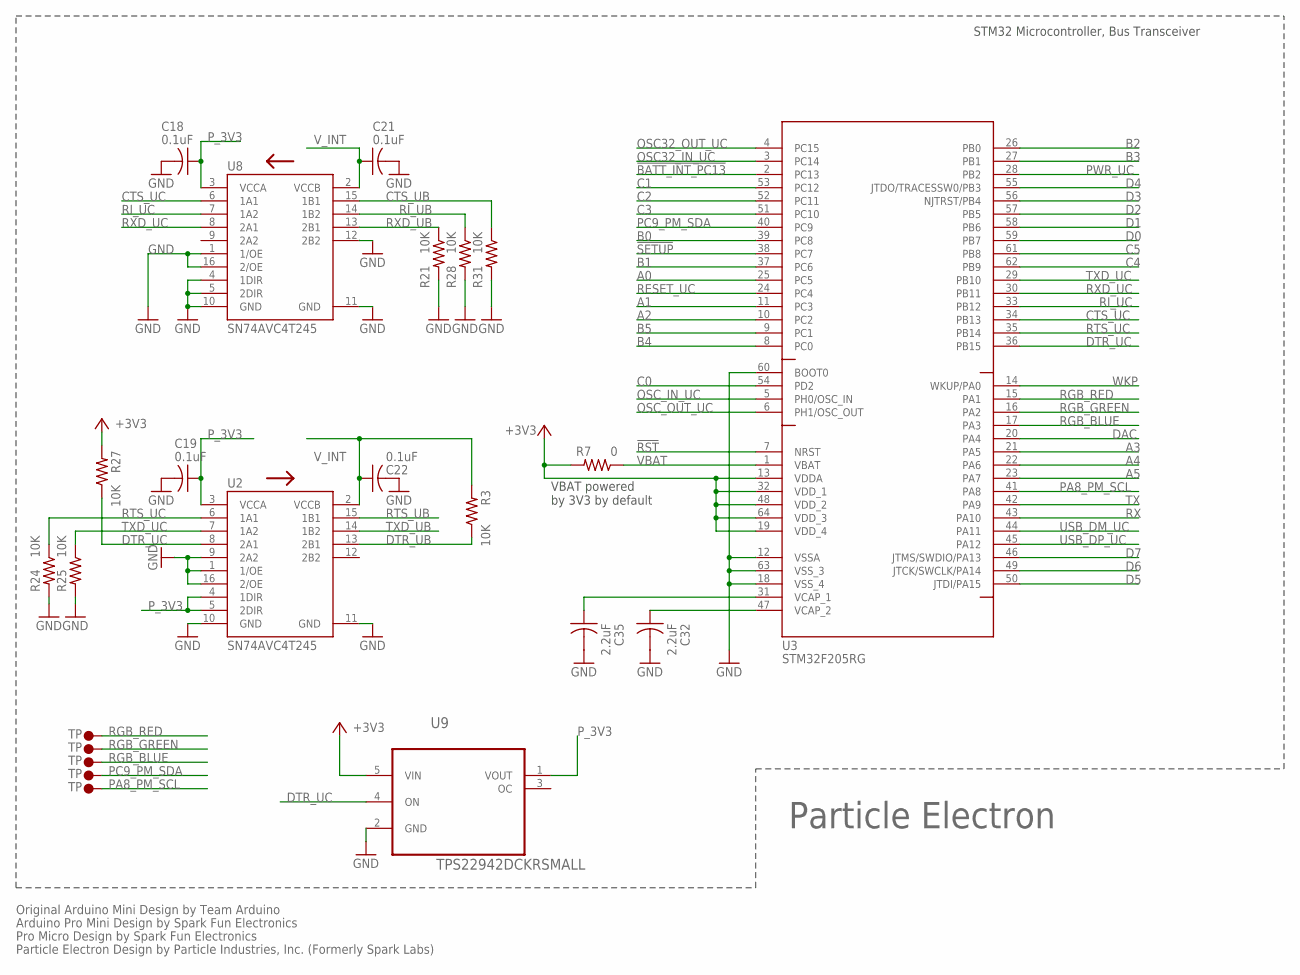
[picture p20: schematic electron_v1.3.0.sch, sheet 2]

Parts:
C18, C19, C21, C22: 0.1uF; C0402_B
C32, C35: 2.2uF; C0402_B
R3, R21, R24, R25, R27, R28, R31: 10K; R0402_B
R7: 0; R0402_B
U2, U8: SN74AVC4T245; UFQFN-16
U3: STM32F205RG; LQFP64
U9: TPS22942DCKRSMALL; SC70-5
U$8, U$9, U$11, U$12, U$13: TP0; TP30_BOT

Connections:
!BATT_INT_PC13: U3.2 (PC13); also elsewhere on the board
!RST: U3.7 (NRST); also elsewhere on the board
!SETUP: U3.38 (PC7); also elsewhere on the board
+3V3: R7.2, R27.2, U3.13 (VDDA), U3.19 (VDD_4), U3.32 (VDD_1), U3.48 (VDD_2), U3.64 (VDD_3), U9.5 (VIN); also elsewhere on the board
A0: U3.25 (PC5); also elsewhere on the board
A1: U3.11 (PC3); also elsewhere on the board
A2: U3.10 (PC2); also elsewhere on the board
A3: U3.21 (PA5); also elsewhere on the board
A4: U3.22 (PA6); also elsewhere on the board
A5: U3.23 (PA7); also elsewhere on the board
B0: U3.39 (PC8); also elsewhere on the board
B1: U3.37 (PC6); also elsewhere on the board
B2: U3.26 (PB0); also elsewhere on the board
B3: U3.27 (PB1); also elsewhere on the board
B4: U3.8 (PC0); also elsewhere on the board
B5: U3.9 (PC1); also elsewhere on the board
C0: U3.54 (PD2); also elsewhere on the board
C1: U3.53 (PC12); also elsewhere on the board
C2: U3.52 (PC11); also elsewhere on the board
C3: U3.51 (PC10); also elsewhere on the board
C4: U3.62 (PB9); also elsewhere on the board
C5: U3.61 (PB8); also elsewhere on the board
CTS_UB: R31.1, U8.15 (1B1); also elsewhere on the board
CTS_UC: U3.34 (PB13), U8.6 (1A1)
D0: U3.59 (PB7); also elsewhere on the board
D1: U3.58 (PB6); also elsewhere on the board
D2: U3.57 (PB5); also elsewhere on the board
D3: U3.56 (NJTRST/PB4); also elsewhere on the board
D4: U3.55 (JTDO/TRACESSW0/PB3); also elsewhere on the board
D5: U3.50 (JTDI/PA15); also elsewhere on the board
D6: U3.49 (JTCK/SWCLK/PA14); also elsewhere on the board
D7: U3.46 (JTMS/SWDIO/PA13); also elsewhere on the board
DAC: U3.20 (PA4); also elsewhere on the board
DTR_UB: R3.1, U2.13 (2B1); also elsewhere on the board
DTR_UC: R27.1, U2.8 (2A1), U3.36 (PB15), U9.4 (ON)
GND: C18.2, C19.2, C21.2, C22.2, C32.2, C35.2, R21.2, R24.2, R25.2, R28.2, R31.2, U2.1 (1/OE), U2.9 (2A2), U2.10 (GND), U2.11 (GND), U2.16 (2/OE), U3.12 (VSSA), U3.18 (VSS_4), U3.60 (BOOT0), U3.63 (VSS_3), U8.1 (1/OE), U8.4 (1DIR), U8.5 (2DIR), U8.10 (GND), U8.11 (GND), U8.12 (2B2), U8.16 (2/OE), U9.2 (GND); also elsewhere on the board
unnamed: C35.1, U3.31 (VCAP_1)
unnamed: C32.1, U3.47 (VCAP_2)
OSC32_IN_UC: U3.3 (PC14); also elsewhere on the board
OSC32_OUT_UC: U3.4 (PC15); also elsewhere on the board
OSC_IN_UC: U3.5 (PH0/OSC_IN); also elsewhere on the board
OSC_OUT_UC: U3.6 (PH1/OSC_OUT); also elsewhere on the board
PA8_PM_SCL: U3.41 (PA8), U$9.P$1; also elsewhere on the board
PC9_PM_SDA: U3.40 (PC9), U$8.P$1; also elsewhere on the board
PWR_UC: U3.28 (PB2); also elsewhere on the board
P_3V3: C18.1, C19.1, U2.3 (VCCA), U2.4 (1DIR), U2.5 (2DIR), U8.3 (VCCA), U9.1 (VOUT)
RESET_UC: U3.24 (PC4); also elsewhere on the board
RGB_BLUE: U3.17 (PA3), U$13.P$1; also elsewhere on the board
RGB_GREEN: U3.16 (PA2), U$12.P$1; also elsewhere on the board
RGB_RED: U3.15 (PA1), U$11.P$1; also elsewhere on the board
RI_UB: R28.1, U8.14 (1B2); also elsewhere on the board
RI_UC: U3.33 (PB12), U8.7 (1A2)
RTS_UB: U2.15 (1B1); also elsewhere on the board
RTS_UC: R24.1, U2.6 (1A1), U3.35 (PB14)
RX: U3.43 (PA10); also elsewhere on the board
RXD_UB: R21.1, U8.13 (2B1); also elsewhere on the board
RXD_UC: U3.30 (PB11), U8.8 (2A1)
TX: U3.42 (PA9); also elsewhere on the board
TXD_UB: U2.14 (1B2); also elsewhere on the board
TXD_UC: R25.1, U2.7 (1A2), U3.29 (PB10)
USB_DM_UC: U3.44 (PA11); also elsewhere on the board
USB_DP_UC: U3.45 (PA12); also elsewhere on the board
VBAT: R7.1, U3.1 (VBAT); also elsewhere on the board
V_INT: C21.1, C22.1, R3.2, U2.2 (VCCB), U8.2 (VCCB); also elsewhere on the board
WKP: U3.14 (WKUP/PA0); also elsewhere on the board

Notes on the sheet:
Particle Electron
STM32 Microcontroller, Bus Transceiver
Original Arduino Mini Design by Team Arduino
Arduino Pro Mini Design by Spark Fun Electronics
Pro Micro Design by Spark Fun Electronics
Particle Electron Design by Particle Industries, Inc. (Formerly Spark Labs)
VBAT powered by 3V3 by default

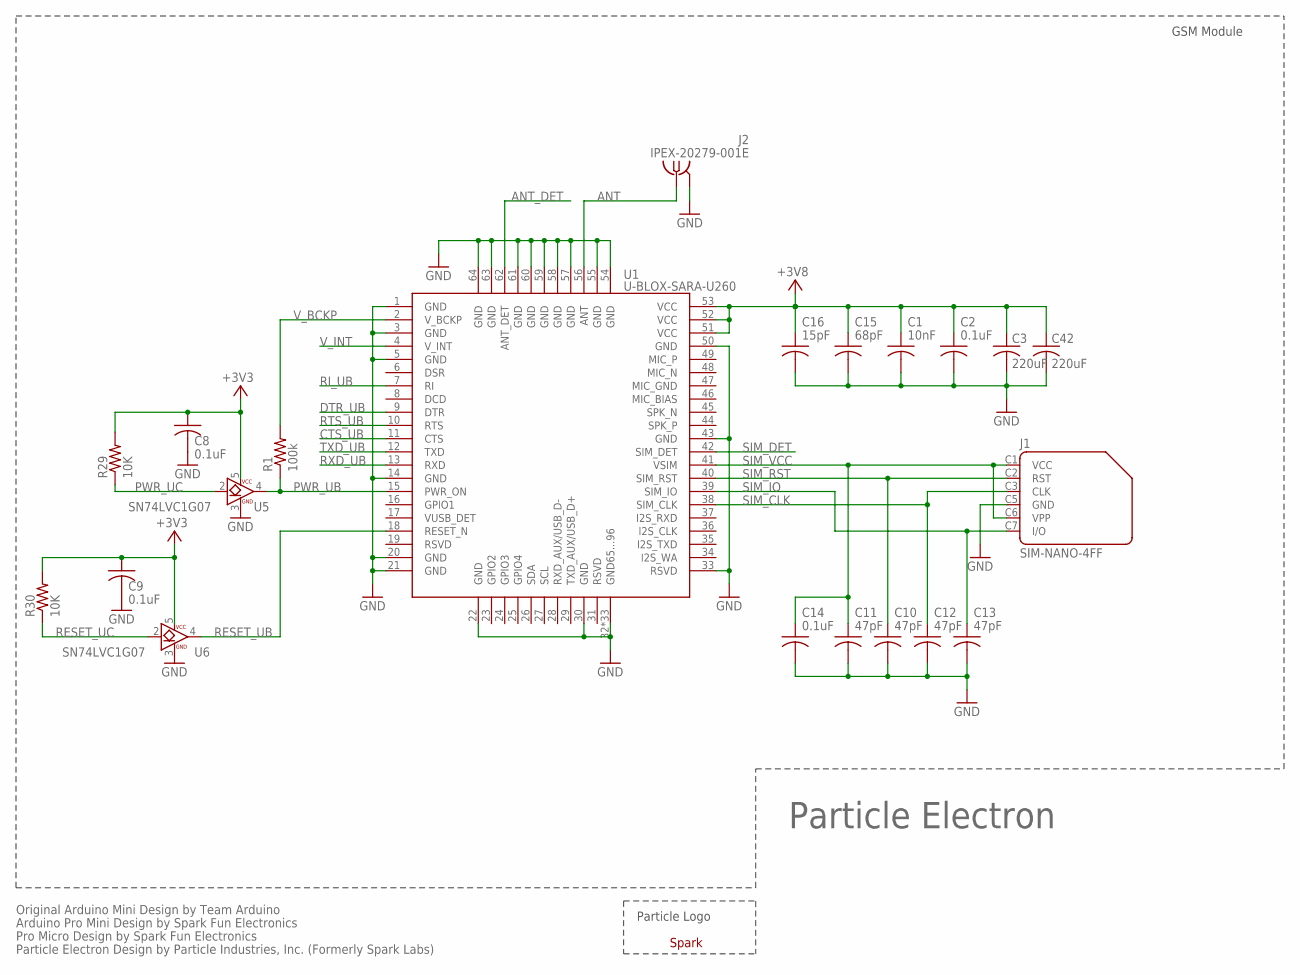
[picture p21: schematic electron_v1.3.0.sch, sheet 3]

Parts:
C1: 10nF; C0402_B
C2, C8, C9, C14: 0.1uF; C0402_B
C3, C42: 220uF; C1210
C10, C11, C12, C13: 47pF; C0402_B
C15: 68pF; C0402_B
C16: 15pF; C0402_B
J1: SIM-NANO-4FF; GCT-SIM8100
J2: IPEX-20279-001E
R1: 100k; R0402_B
R29, R30: 10K; R0402_B
U1: U-BLOX-SARA-U260; U-BLOX-SARA-U2
U5, U6: SN74LVC1G07; SC-70-5
U$2: SPARK_LOGO2

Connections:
+3V3: C8.1, C9.1, R29.2, R30.2, U5.5 (VCC), U6.5 (VCC); also elsewhere on the board
+3V8: C1.1, C2.1, C3.1, C15.1, C16.1, C42.1, U1.51 (VCC), U1.52 (VCC), U1.53 (VCC); also elsewhere on the board
ANT: J2.1, U1.56 (ANT)
ANT_DET: U1.62 (ANT_DET)
CTS_UB: U1.11 (CTS); also elsewhere on the board
DTR_UB: U1.9 (DTR); also elsewhere on the board
GND: C1.2, C2.2, C3.2, C8.2, C9.2, C10.2, C11.2, C12.2, C13.2, C14.2, C15.2, C16.2, C42.2, J1.C5 (GND), J2.2@1 (GND), J2.2@2 (GND), U1.1 (GND), U1.3 (GND), U1.5 (GND), U1.14 (GND), U1.20 (GND), U1.21 (GND), U1.22 (GND), U1.30 (GND), U1.32 (GND65...96), U1.33 (RSVD), U1.43 (GND), U1.50 (GND), U1.54 (GND), U1.55 (GND), U1.57 (GND), U1.58 (GND), U1.59 (GND), U1.60 (GND), U1.61 (GND), U1.63 (GND), U1.64 (GND), U1.65 (GND65...96), U1.66 (GND65...96), U1.67 (GND65...96), U1.68 (GND65...96), U1.69 (GND65...96), U1.70 (GND65...96), U1.71 (GND65...96), U1.72 (GND65...96), U1.73 (GND65...96), U1.74 (GND65...96), U1.75 (GND65...96), U1.76 (GND65...96), U1.77 (GND65...96), U1.78 (GND65...96), U1.79 (GND65...96), U1.80 (GND65...96), U1.81 (GND65...96), U1.82 (GND65...96), U1.83 (GND65...96), U1.84 (GND65...96), U1.85 (GND65...96), U1.86 (GND65...96), U1.87 (GND65...96), U1.88 (GND65...96), U1.89 (GND65...96), U1.90 (GND65...96), U1.91 (GND65...96), U1.92 (GND65...96), U1.93 (GND65...96), U1.94 (GND65...96), U1.95 (GND65...96), U1.96 (GND65...96), U5.3 (GND), U6.3 (GND); also elsewhere on the board
PWR_UB: R1.1, U1.15 (PWR_ON), U5.4 (B)
PWR_UC: R29.1, U5.2 (A); also elsewhere on the board
RESET_UB: U1.18 (RESET_N), U6.4 (B)
RESET_UC: R30.1, U6.2 (A); also elsewhere on the board
RI_UB: U1.7 (RI); also elsewhere on the board
RTS_UB: U1.10 (RTS); also elsewhere on the board
RXD_UB: U1.13 (RXD); also elsewhere on the board
SIM_CLK: C12.1, J1.C3 (CLK), U1.38 (SIM_CLK)
SIM_DET: U1.42 (SIM_DET)
SIM_IO: C13.1, J1.C7 (I/O), U1.39 (SIM_IO)
SIM_RST: C10.1, J1.C2 (RST), U1.40 (SIM_RST)
SIM_VCC: C11.1, C14.1, J1.C1 (VCC), J1.C6 (VPP), U1.41 (VSIM)
TXD_UB: U1.12 (TXD); also elsewhere on the board
V_BCKP: R1.2, U1.2 (V_BCKP)
V_INT: U1.4 (V_INT); also elsewhere on the board

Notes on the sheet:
Particle Electron
GSM Module
Particle Logo
Original Arduino Mini Design by Team Arduino
Arduino Pro Mini Design by Spark Fun Electronics
Pro Micro Design by Spark Fun Electronics
Particle Electron Design by Particle Industries, Inc. (Formerly Spark Labs)

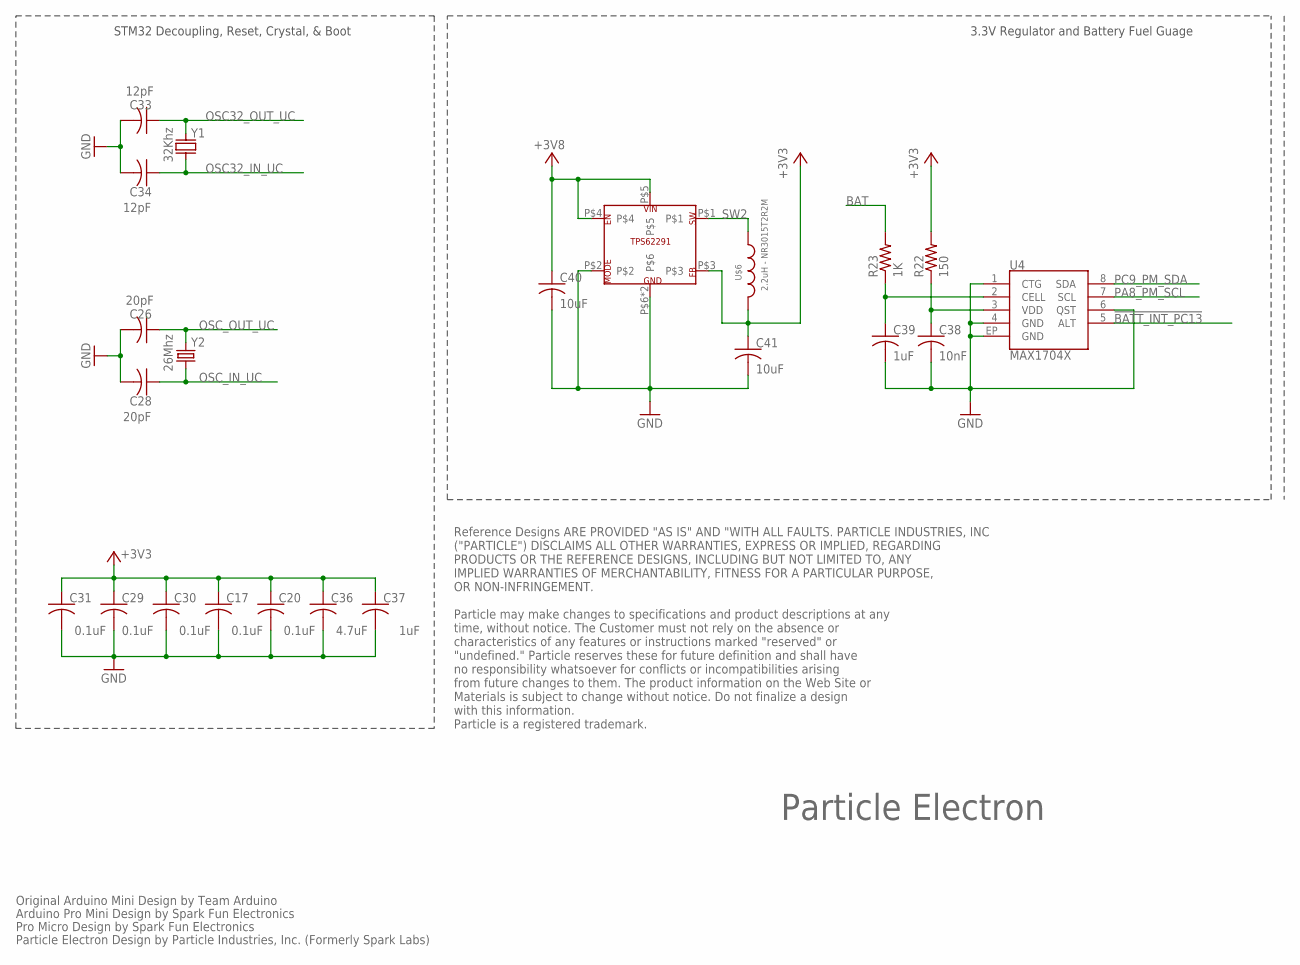
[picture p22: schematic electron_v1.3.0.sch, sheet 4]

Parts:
C17, C20, C29, C30, C31: 0.1uF; C0402_B
C26, C28: 20pF; C0402_B
C33, C34: 12pF; C0402_B
C36: 4.7uF; C0402_B
C37, C39: 1uF; C0402_B
C38: 10nF; C0402_B
C40, C41: 10uF; C0603_B
R22: 150; 0603-RES
R23: 1K; 0603-RES
U4: MAX1704X; TDFN-8
U$5: TPS62291DRV; S-PWSON-N6
U$6: 2.2uH - NR3015T2R2M; INDUCTOR-NR3015
Y1: 32Khz; FC135
Y2: 26Mhz; CRYSTAL-SMD-5X3

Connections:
!BATT_INT_PC13: U4.5 (ALT); also elsewhere on the board
+3V3: C17.1, C20.1, C29.1, C30.1, C31.1, C36.1, C37.1, C41.1, R22.2, U$5.P$3, U$6.2; also elsewhere on the board
+3V8: C40.1, U$5.P$4, U$5.P$5; also elsewhere on the board
BAT: R23.2; also elsewhere on the board
GND: C17.2, C20.2, C26.2, C28.2, C29.2, C30.2, C31.2, C33.2, C34.2, C36.2, C37.2, C38.2, C39.2, C40.2, C41.2, U4.1 (CTG), U4.4 (GND), U4.6 (QST), U4.EP (GND), U$5.P$2, U$5.P$6, U$5.TP; also elsewhere on the board
unnamed: C39.1, R23.1, U4.2 (CELL)
unnamed: C38.1, R22.1, U4.3 (VDD)
OSC32_IN_UC: C34.1, Y1.X1 (1); also elsewhere on the board
OSC32_OUT_UC: C33.1, Y1.X2 (2); also elsewhere on the board
OSC_IN_UC: C28.1, Y2.1; also elsewhere on the board
OSC_OUT_UC: C26.1, Y2.3 (2); also elsewhere on the board
PA8_PM_SCL: U4.7 (SCL); also elsewhere on the board
PC9_PM_SDA: U4.8 (SDA); also elsewhere on the board
SW2: U$5.P$1, U$6.1

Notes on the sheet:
Particle Electron
STM32 Decoupling, Reset, Crystal, & Boot
3.3V Regulator and Battery Fuel Guage
Original Arduino Mini Design by Team Arduino
Arduino Pro Mini Design by Spark Fun Electronics
Pro Micro Design by Spark Fun Electronics
Particle Electron Design by Particle Industries, Inc. (Formerly Spark Labs)
Reference Designs ARE PROVIDED "AS IS" AND "WITH ALL FAULTS. PARTICLE INDUSTRIES, INC ("PARTICLE") DISCLAIMS ALL OTHER WARRANTIES, EXPRESS OR IMPLIED, REGARDING PRODUCTS OR THE REFERENCE DESIGNS, INCLUDING BUT NOT LIMITED TO, ANY IMPLIED WARRANTIES OF MERCHANTABILITY, FITNESS FOR A PARTICULAR PURPO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

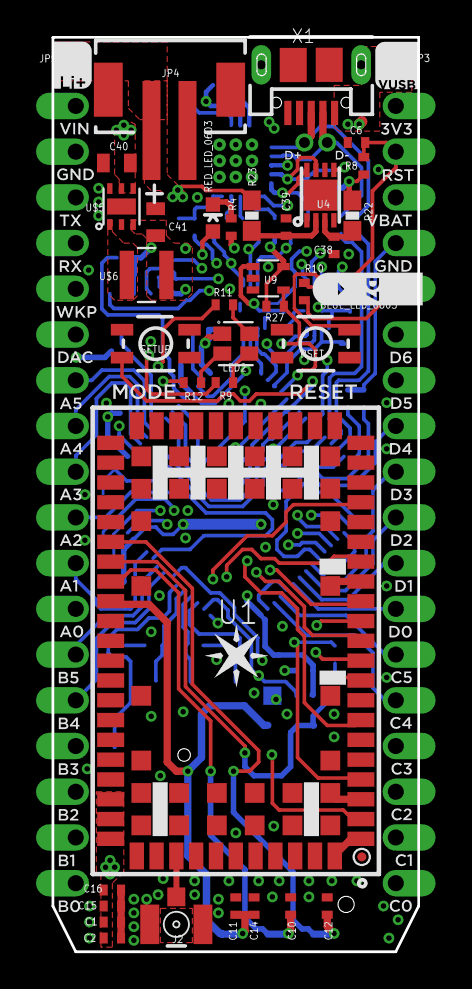
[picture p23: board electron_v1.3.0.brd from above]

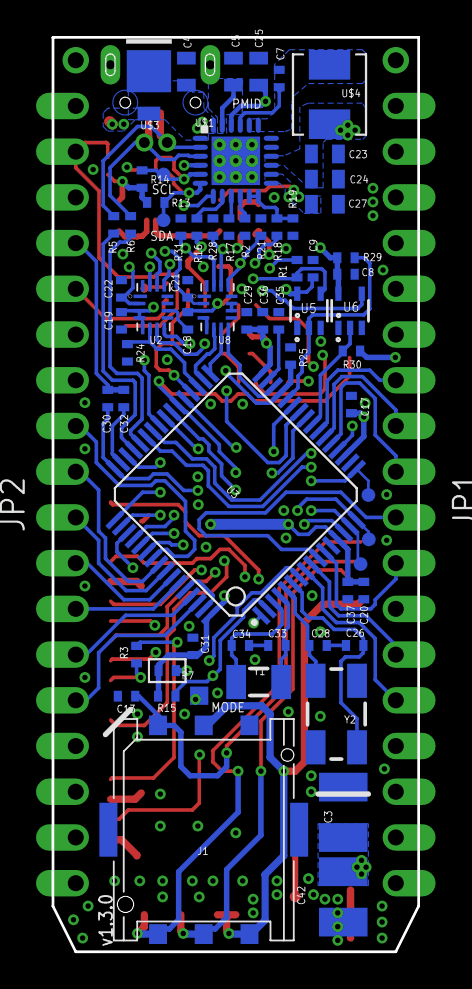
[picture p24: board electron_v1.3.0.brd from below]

Board: 4 copper layers, 20.3 x 50.8 mm, 106 parts (62 on the bottom side), 96 nets.

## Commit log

2015-07-29 Added 'Particle.lbr' Eagle Library
    [electron_v009.brd, electron_v009.sch]
2015-07-29 Added latest 'electron_v009' Eagle design folder/files (PCB Ver: 009)
    [electron_v009.brd, electron_v009.sch]
2015-07-29 Added Manufacturing Gerber files for 'electron_v009'
    [electron_v009.GBL, electron_v009.GBO, electron_v009.GBP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]
2015-07-29 Added 'electron_v010' with improved RF layout & additional GND Vias
    [electron_v010.brd, electron_v010.sch]
2015-07-29 Adding a BOM for v010
    Adding a BOM for the most current version of the Electron
    [electron-bom-v010.xlsx]
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2015-07-30 #8 Updated 3.3V regulator's inductor package footprint
    [electron_v010.brd, electron_v010.sch]
2015-07-30 #7 Changed Button labels to SETUP and RESET
    [electron_v010.brd]
2015-07-30 #4 USB 5V exposed via hexagonal pad on top right corner above 3V3 pin
    [electron_v010.brd, electron_v010.sch]
2015-07-30 #5 Added header pin labels that are not obscured by the u-blox module
    [electron_v010.brd]
2015-07-30 #1 Added u-blox positioning silkscreen
    [electron_v010.brd]
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2015-07-31 #2 Replaced M18 round header pads with D-shaped pads and re-routed
    [electron_v010.brd, electron_v010.sch]
2015-07-31 #10 ANT trace width @ RF net rules & deleted IPEX polygon cutouts
    [electron_v010.brd, electron_v010.sch]
2015-07-31 #9 Added cutout on top layer under the ANT connector
    [electron_v010.brd]
2015-07-31 #13 Added more GND Vias around ANT connector and updated trace routes
    [electron_v010.brd, electron_v010.sch]
2015-07-31 #11 Additional Vias added for battery trace connections
    [electron_v010.brd, electron_v010.sch]
2015-07-31 #12 Updated to bigger pads PMIC inductor footprint and power polygons
    [electron_v010.brd, electron_v010.sch]
2015-07-31 Updated 5V header pad to round with drill size same as other headers
    [electron_v010.brd, electron_v010.sch]
2015-07-31 Added more Vias on u-blox 3.8V trace connection (PCB Ver: 010 Ready)
    [electron_v010.brd]
2015-07-31 #15 Added Manufacturing Gerber files for 'electron_v010'
    [electron_v010.GBL, electron_v010.GBO, electron_v010.GBP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]
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2015-07-31 Updated Gerbers for PCB Ver 010
    [electron_v010.GTO]
2015-07-31 added pin labels, thickened the text and moved particle logo
    [electron_v010.brd]
2015-07-31 generated new gerber files after adding pin labels
    [electron_v010.GBL, electron_v010.GBO, electron_v010.GBP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]
2015-07-31 Added specs for passives, some dottiest
    Check it out, yo
    [electron-bom-v010-150731.xlsx, electron-bom-v010.xlsx]
2015-08-01 Added some mfg documents for spinning up beta boards
    Added fab specs, 50 ohm impedance calcs, rf net PDF, and layer stackup
    explanation
    [electron-v010-fab-specs.xlsx]
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2015-08-05 Added 'electron_v011' Eagle design folder/files (Work in Progress)
    [electron_v011.brd, electron_v011.sch]
2015-08-05 BOM updated with passive values, some packaging stuff
    See the changelogzorzzzz :-)
    [electron-bom-v010-150803.xlsx, electron-bom-v010-150805.xlsx]
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2015-08-07 Updated BOM (C5 value from 20uF to 22uF)
    [electron-bom-v010-150805.xlsx, electron-bom-v010-150807.xlsx]
2015-08-12 Updated BOM
    changed the quantity field of some passive components to match the
    correct number of designators.
    [electron-bom-v010-150807.xlsx, electron-bom-v010-150812.xlsx]
2015-08-19 Replaced LM3281 with TPS62291 in schematic and updated circuit
    [electron_v011.brd, electron_v011.sch]
2015-08-19 2.2uH inductor reused for 3.3V circuit, components placed and locked
    [electron_v011.brd, electron_v011.sch]
2015-08-19 Completed v011 PCB routing for revised 3.3V power circuit #19
    [electron_v011.brd, electron_v011.sch]
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2015-08-19 Added orientation indicators to the silkscreen layers #17
    [electron_v011.brd]
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2015-08-20 Updated BOM
    New voltage regulator, new power inductor, cross parts for passives.
    [electron-bom-v010-150812.xlsx, electron-bom-v011-150820.xlsx]
2015-08-21 Added 'electron_v012' files-changed 3V3 power inductor footprint #21
    [electron_v012.brd, electron_v012.sch]
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2015-08-24 Updated Electron BOM
    removed extra part numbers from the antenna line
    [electron-bom-v011-150820.xlsx, electron-bom-v011-150823.xlsx]
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2015-08-27 added lipo and pmid 5v header
    change log:
    1. Exposed LiPo connection via a header
    2. Exposed PMID boost 5V via a header
    3. Lowered the 3V3 inductor and rotated its output cap to meet
    datasheet recommendations
    [electron_v012.brd, electron_v012.sch]
2015-08-31 Updated Electron BOM
    Only includes Yageo/Samsung parts instead of Fenghua cross parts that
    did not meet spec.
    [electron-bom-v011-150823.xlsx, electron-bom-v012-150831.xlsx]
2015-09-02 Updated BOM
    Moved battery part from separate SKU to same BOM as Electron
    [electron-bom-v012-150831.xlsx, electron-bom-v012-150901.xlsx]
2015-09-03 Delete electron_v013.brd
    Delete this file because of my wrong operation
    [electron_v013.brd]
2015-09-03 Delete electron_v013.sch
    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
    [electron_v013.sch]
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2015-10-26 updated bom to 151026 - resistor count changes
    [electron-bom-v015-150922.xlsx, electron-bom-v015-151026.xlsx]
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2015-11-02 updated BOM to v017-151102
    10K resistor qty from 12 to 13
    4K7 resistor qty from 3 to 2
    0R resistors deleted (3 to 0)
    [electron-bom-v016-151026.xlsx, electron-bom-v017-151102.xlsx]
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2015-11-30 Pushing updated BOM so @mohitbhoite can make changes
    Hooray!
    [electron-bom-v017-151102.xlsx, electron-bom-v020-151119.xlsx]
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2015-12-08 Added SIM card sticker in 12/8 revision of the BOM
    [electron-bom-v020-151130.xlsx, electron-bom-v020-151208.xlsx]
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

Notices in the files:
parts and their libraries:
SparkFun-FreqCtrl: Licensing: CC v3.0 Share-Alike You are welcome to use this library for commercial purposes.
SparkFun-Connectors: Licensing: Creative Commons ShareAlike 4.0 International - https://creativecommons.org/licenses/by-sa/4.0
